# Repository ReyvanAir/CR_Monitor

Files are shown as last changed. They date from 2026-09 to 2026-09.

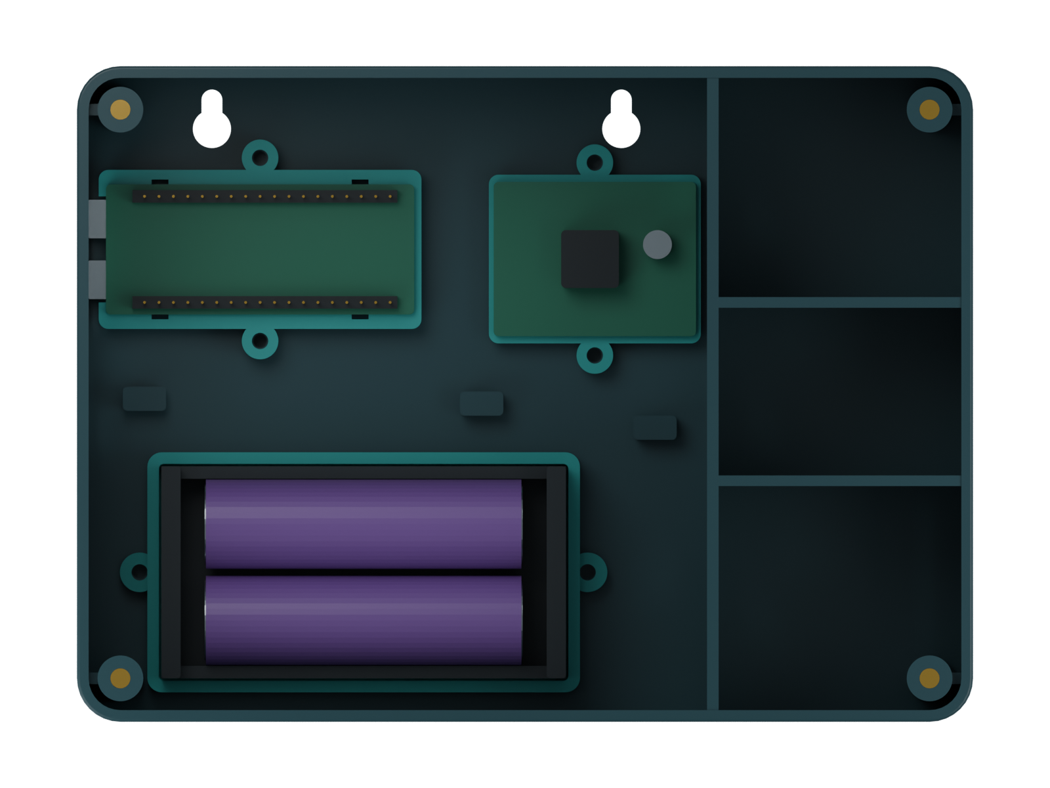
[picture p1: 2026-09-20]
CR_Monitor_Enclosure/previews/03_internal_layout.png

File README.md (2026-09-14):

# Classroom Environment Monitor

An IoT system that measures classroom conditions — temperature, humidity, light and
sound level — and pairs those objective readings with anonymous human feedback, so
decisions about the learning environment can be based on evidence rather than guesswork.

An ESP32-S3 node samples its sensors and publishes JSON telemetry over MQTT. A local
Docker stack (Mosquitto → Node-RED → InfluxDB → Grafana) validates, stores and
visualises the stream.

## Documentation

**[Read the full documentation](https://reyvanair.github.io/CR_Monitor/)**

Five parts, covering the whole build:

| | |
|---|---|
| [Overview](https://reyvanair.github.io/CR_Monitor/) | Architecture, what it measures, project stages |
| [Pins & wiring](https://reyvanair.github.io/CR_Monitor/hardware.html) | Full GPIO map, sensors, display shield |
| [Firmware](https://reyvanair.github.io/CR_Monitor/firmware.html) | Boot order, sampling loop, sound maths, alarms |
| [MQTT contract](https://reyvanair.github.io/CR_Monitor/mqtt.html) | Topics, payload schema, retained state |
| [Build & bring-up](https://reyvanair.github.io/CR_Monitor/setup.html) | Toolchain, flashing, calibration, backend |

The same pages are in [`docs/`](docs/) and open offline straight from the filesystem.

## Hardware

| Part | Function | Connection |
|---|---|---|
| ESP32-S3 DevKitC-1 (N16R8) | Controller | — |
| SHT3x | Temperature + humidity | I²C `0x44` — SDA `GPIO8`, SCL `GPIO9` |
| BH1750 | Illuminance (lux) | I²C `0x23` — same bus |
| MAX4466 | Sound level (dB) | `GPIO5` (ADC1), **3.3 V only** |
| Piezo buzzer | Threshold alert | `GPIO7` |

The mic must stay on an ADC1 pin — ADC2 stops working whenever Wi-Fi is on. Full
wiring notes, rationale and the history of dropped parts (DHT22, the dead I²C LCD)
are in [`CR_Monitor_NOTES.txt`](CR_Monitor_NOTES.txt).

## Privacy

Sound is captured as a **decibel level only**. No audio is recorded, buffered or
transmitted. Occupancy is likewise reported as a bucket (Unoccupied / Low / Medium /
High) rather than a headcount. Both are deliberate design choices, not limitations.

## Repository layout

```
CR_Monitor/CR_Monitor.ino   ESP32-S3 sketch — sensors, Wi-Fi, MQTT
CR_Monitor_NOTES.txt        Design notes: wiring, decisions, the "why"
SETUP_GUIDE.txt             Step-by-step build and deployment guide
docs/                       Project documentation (HTML, also served as a site)
docker-compose.yml          Mosquitto + InfluxDB + Node-RED + Grafana
mosquitto.conf              Broker config (anonymous — LAN use only)
diagram.json                Wokwi simulation layout
```

## Getting started

**1 — Flash the node.** Open `CR_Monitor/CR_Monitor.ino` in the Arduino IDE as board
*ESP32S3 Dev Module* (PSRAM: OPI, Flash: 16 MB). Install the `Adafruit SHT31`,
`BH1750` and `PubSubClient` libraries, then fill in the config at the top:

```cpp
const char* WIFI_SSID     = "YOUR_WIFI_SSID";
const char* WIFI_PASSWORD = "YOUR_WIFI_PASSWORD";
const char* MQTT_HOST     = "192.168.1.5";   // your broker's LAN IP
const char* ROOM_ID       = "room-101";
```

**2 — Start the backend.**

```bash
docker compose up -d
```

Grafana lands on <http://localhost:3000> (`admin` / `admin`), Node-RED on
<http://localhost:1880>, InfluxDB on <http://localhost:8086>.

**3 — Watch the data.** Telemetry publishes to `classroom/<room>/<node>/telemetry`,
with `status` and `alert` on sibling topics.

`SETUP_GUIDE.txt` walks through all of this in detail, including the Node-RED flow
and the InfluxDB token setup.

## Security note

The credentials in the sketch are placeholders — put your own in locally and keep
them out of commits. The broker ships with `allow_anonymous true` for convenience on
a trusted LAN; add authentication before deploying anywhere real.

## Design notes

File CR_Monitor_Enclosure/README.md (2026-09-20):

# CR Monitor enclosure — revision A

Editable Blender 4.5 LTS enclosure for the hardware documented at [Classroom Environment Monitor](https://reyvanair.github.io/CR_Monitor/), revision 2026-09-13.

**Status: dimensioned prototype.** The documentation identifies the hardware and wiring but does not supply mechanical drawings, breakout-board variants, a battery holder, or a battery power circuit. The component sizes below are explicit design assumptions. Digital mesh and interference checks do not establish a physical fit.

## Open the design

Open **CR_Monitor_Enclosure.blend** in Blender 4.5 or newer. The active scene is `CR Monitor | assembled`.

- **Frame 1:** assembled enclosure. **Frame 80:** exploded view. Drag the timeline between them to open the assembly.
- Press **Numpad 0** for the camera view. Camera markers switch between the assembled and exploded cameras.
- Collections `01`, `02`, and `03` contain the printable parts.
- Collections `04` and `05` contain reference hardware and visual legends. They are not printable components.
- Collection `06` contains hidden wireframe fit envelopes. Unhide its objects to inspect the assumed spaces, at frame 1.
- Read `START HERE — design notes` in Blender's Text Editor. The generator is also embedded as `build_enclosure.py`.

The model uses **millimetres**. STL files are already centered and placed on Z = 0 in their intended print orientations. The front bezel is exported face down. Do not apply an additional 1,000× conversion when importing an STL into a slicer.

## Dimensions and layout

| Feature | Design value |
|---|---:|
| Outside enclosure, width × height × depth | **186 × 136 × 62 mm** |
| Rear shell side walls / rear floor | 2.4 / 3.0 mm |
| Front face thickness | 3.0 mm |
| Seam between shell and face | 0.30 mm |
| Registration skirt clearance | 0.35 mm per side |
| LCD opening, landscape | 76 × 51 mm |
| Shared ESP32 USB opening, height × width along the left wall | 16 × 31 mm |
| Separate power-cable opening, height × width | 10 × 14 mm |
| BH1750 opening | 22 × 16 mm |
| MAX4466 sound port | 8 mm diameter |
| SHT3x front grille | Seven 29 × 2 mm slots |
| Buzzer cup / assumed buzzer | 13.4 mm bore / 12 mm diameter |
| Rear wall-mount keyholes | 85 mm horizontal spacing; 8 mm entry, 4.4 mm neck |

The TFT occupies the upper left of the front. The ESP32 sits behind it, with USB connections on the left. The battery holder sits lower left. A separate carrier above the batteries reserves space for the chosen power electronics. Three compartments on the right place BH1750 at the top, MAX4466 in the middle, and SHT3x at the bottom. The temperature/humidity compartment has front, side and bottom vents, separated from the main electronics by a wall with small wire passages.

## Measure these parts before printing

These are **assumed envelopes**, not dimensions verified against your physical parts. Sensor names refer to the full breakout boards, not just their ICs.

| Part | Assumed size / position | Required fit check |
|---|---|---|
| ILI9481 3.5-inch Uno-style shield | PCB 98 × 64 × 1.6 mm; glass 84 × 57 × 4.6 mm; active area 73.9 × 49.3 mm | Measure PCB, glass, active-area offset, all headers and plugged-in connector depth. |
| ESP32-S3 DevKitC-1 N16R8 | PCB 64 × 27 mm | Measure the board, USB positions, header direction, shield thickness and buttons. |
| Purchased two-cell 18650 holder | 84 × 44 × 23 mm maximum nominal envelope | Measure the complete insulated holder with the chosen cells installed, including contacts and leads. |
| Two cell proxies | Diameter 18.6 mm; length 65.5 mm | Protected/button-top cells may be longer. The actual holder determines compatibility. |
| BH1750 breakout | 31 × 16 mm | Verify the light-sensitive element lines up with the opening. |
| MAX4466 breakout | 20 × 14 mm; capsule 9.6 mm diameter × 5.5 mm high | Verify capsule position, gain trimmer, headers and gasket clearance. |
| SHT3x breakout | 23 × 18 mm | Verify sensing element and connector positions; leave the sensing area uncovered. |
| Power electronics | Reserved envelope 42 × 32 × 20 mm | Choose and measure the real module(s), including wires. This is not a specified charger design. |

The TFT's assumed connected-header envelope reaches 19 mm below its PCB, to Z = 33.6 mm. The holder envelope ends at Z = 30.4 mm; the ESP32 wire envelope ends at Z = 27 mm. These leave **3.2 mm** and **6.6 mm** respectively in depth, before any additional cable bends. Check the real plug housings and route the wiring in the open channels. An overall clearance is not a guarantee that every connector orientation fits.

The ESP32 is mounted **component side toward the rear, long header pins toward the TFT**. Its open carrier clears the underside module and USB bodies. Two small rear probe holes assume button centers at X = −78 mm, Y = 25 and 35 mm. Move or omit these holes if your button locations differ. Keep the antenna end clear of the power module, cells and bundled wiring.

## Printable parts

Print one of each of the **12 STL files**:

| Files | Purpose |
|---|---|
| `01_rear_tray.stl` | Rear shell, reinforced case bosses, partitions, vents, rear keyholes and mount bosses |
| `02_front_bezel.stl` | LCD and sensor openings, registration skirt, display/sensor posts and buzzer cup |
| `03_battery_cradle.stl` | Removable cradle for the purchased insulated holder; two strap positions |
| `04_esp32_carrier.stl` | Open carrier, USB relief and tie slots |
| `05_power_carrier.stl` | Separate removable power-module carrier |
| Four `06_tft_clamp_*.stl` files | Slotted PCB-edge retainers; approximately ±1.5 mm screw travel |
| Three `07_*_carrier.stl` files | Sensor-specific open carriers, edge guides and tie slots |

PETG is a reasonable prototype material. A starting slicer setup is a 0.4 mm nozzle, 0.2 mm layers, four walls and five top/bottom layers. Adjust supports for the horizontal vent/USB bridges after checking your slicer preview. The main parts fit within a nominal 220 × 220 mm print bed. Printed legends and the sample screen are visualizations only; they are not raised lettering in the STL files.

The four main case bosses have **4.2 mm bores, 5.7 mm deep**, for suitably sized M3 heat-set inserts. Match the bores to the actual insert manufacturer's specification. Internal mount pilots are nominally 2.8 mm: confirm grip with the selected M3 plastic thread-forming screws and printed material before assembly. Do not assume every M3 screw/insert has the same fit.

## Assembly

1. Check dimensions and slicer scale, then test-print the smallest relevant carrier/clamp before the shells. Verify the intended screw/insert fit on scrap material.
2. Install the four M3 case inserts. Install the ESP32 and power carriers. Secure electronics at clear PCB edges with nonconductive ties, appropriate shims and insulation; keep solder joints off printed supports.
3. Fit the purchased holder in its cradle. Use straps through the side-wall passages. The printed cradle supplies mechanical retention, **not electrical contacts**.
4. Place the display behind the front bezel. Use a thin compressible strip at the glass perimeter and approximately 0.2 mm shims between the PCB back and retaining fingers. Adjust the four fingers to touch bare PCB edges, clear of components, headers and the active touch surface. Tighten gently.
5. Attach the three sensors to their carriers and align the sensing elements with their openings. Use narrow nonconductive ties at the provided edge positions. Keep the SHT3x unobstructed. A soft gasket around the microphone capsule can couple it to the port. Secure the piezo in its cup using suitable foam tape.
6. Route sensor wires through the partition passages. Keep the parallel TFT bus short, allow enough movement to service the front, and use the documented grounds. Route the chosen power input through the separate cable opening and secure the cable to a nearby anchor.
7. Check all connectors and wire bends with the bezel resting in place. Close with four appropriately sized M3 countersunk screws. Fit wall screws to the rear keyholes, or stand the enclosure on its bottom edge with vents unobstructed.

Suggested fasteners are **starting selections to verify**, not a guarantee for every screw head or printed thread: four M3 × 10 countersunk case screws; four M3 × 8 TFT clamp screws; two M3 × 6 BH1750 screws; two M3 × 8 SHT3x screws; two M3 × 10 MAX4466 screws. Rear carrier and cradle screws need short engagement; use washers as necessary and check blind-hole depth so the tips cannot bottom out or penetrate the rear floor. Hardware, ties, gaskets and insulation are not supplied as printable parts.

## Electrical and sensing integration

The [hardware documentation](https://reyvanair.github.io/CR_Monitor/hardware.html) specifies SHT3x and BH1750 on GPIO8/9, MAX4466 on GPIO5 and the buzzer on GPIO7. The ILI9481 shield uses the documented parallel bus, a 5 V backlight supply and, for this particular shield, a separate 3.3 V logic supply. The enclosure does not change those connections.

The source does **not** specify how the two 18650 cells are connected or charged. Select a compatible insulated holder, cell arrangement, protection/charging and regulated supply before assembly. Do not connect the raw cells directly to a rail labeled 5 V or 3V3. The power-board shape in Blender only reserves space.

After assembly, compare SHT3x readings with an external reference during warm-up, recheck light readings in the intended mounting orientation, and recalibrate the microphone with the case closed. Check whether the buzzer affects sound readings. Do not cover the BH1750 opening with tinted plastic without validating its effect. The open sensor ports make this an indoor ventilated prototype, not a weatherproof enclosure.

## Edit and regenerate

Edit the `P` dictionary in `build_enclosure.py`, then run it in Blender's Scripting workspace or with `blender --background --python build_enclosure.py`. The script creates a new scene and preserves existing scenes. `CR_MONITOR_OUTPUT` can specify an output folder. Set `render` to `False` to skip preview renders.

`parameters.json` is an exported record of assumptions; editing that JSON alone does not regenerate the model. Major changes to board sizes, depth or layout also require checking the carrier positions, posts, connector openings and wire spaces in the script. Always re-inspect the assembled result after edits.

`validation_report.json` records digital checks of closed meshes, connected solids, normals, modeled part interference and the exploded animation. It does not certify print tolerances, physical component fit, thermal performance or battery behavior.

Sources: [overview](https://reyvanair.github.io/CR_Monitor/), [pins and hardware](https://reyvanair.github.io/CR_Monitor/hardware.html), [firmware](https://reyvanair.github.io/CR_Monitor/firmware.html), and [display wiring notes](https://github.com/reyvanair/CR_Monitor/blob/main/WIRING_TFT.md). Read on 2026-09-14.

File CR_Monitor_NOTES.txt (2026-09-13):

======================================================================
CR_Monitor - DESIGN NOTES
Classroom Environment Monitor, Stage 2 (real hardware)
======================================================================

This file holds the "why" that used to live as long comments inside
CR_Monitor.cpp. The code now only carries short section headers
(PINS, WI-FI, MQTT, SOUND, ...). Read this alongside it.

Board:  ESP32-S3 DevKitC-1 (N16R8)
  Arduino IDE:  Tools > Board > "ESP32S3 Dev Module"
                PSRAM: "OPI PSRAM"   Flash Size: "16MB"

Libraries (Library Manager):
  - Adafruit SHT31 Library   (Adafruit)      + Adafruit BusIO
  - BH1750                    (Christopher Laws)
  - PubSubClient              (Nick O'Leary)

----------------------------------------------------------------------
1. WIRING
----------------------------------------------------------------------

I2C bus - SDA = GPIO8, SCL = GPIO9:
    SHT3x    addr 0x44 (ADDR->GND) or 0x45 (ADDR->VDD)   power 3.3V
    BH1750   addr 0x23 (ADDR->GND) or 0x5C (ADDR->VDD)   power 3.3V
  Both wired straight to GPIO 8/9 on the 3.3V side.
  Run the I2C bus at 100 kHz (Wire.setClock(100000)).

MAX4466 microphone:
    VCC -> 3.3V   (NOT 5V - the output centres at VCC/2; on 5V it
                   swings past the ESP32 ADC's 3.3V limit and can
                   damage the pin)
    OUT -> GPIO5  (MIC_PIN)
    GND -> GND    (must share ground with the ESP32)

  GPIO5 must be an ADC1 pin. ADC2 stops working whenever Wi-Fi is on,
  so the mic cannot move to an ADC2 pin.

Buzzer:
    + -> GPIO7 (BUZZER_PIN)
    - -> GND
  A piezo buzzer can be driven directly. A magnetic buzzer needs a
  transistor plus a flyback diode.

LCD (currently NOT used):
  The 20x4 I2C LCD backpack is dead / not wired. Everything it used to
  show is printed to the Serial monitor instead (the "status panel").
  The backpack also pulls SDA/SCL to 5V and the ESP32-S3 is not 5V
  tolerant - if the LCD comes back it needs a bidirectional level
  shifter between GPIO 8/9 and the LCD (LV->3V3, HV->5V, common GND),
  with the SHT3x and BH1750 staying on the 3.3V side.
  To re-enable: add <LiquidCrystal_I2C.h>, the lcd object, lcd.init()
  in setup(), and feed the panel fields to lcd rows.

History: the DHT22 was removed. The SHT3x replaces it and speaks I2C,
which got rid of the bit-banged timing that never worked reliably on
the ESP32-S3. GPIO4 and GPIO6 are now free.

----------------------------------------------------------------------
2. PINS  (matches the PINS block in the code)
----------------------------------------------------------------------

  I2C_SDA    = 8
  I2C_SCL    = 9
  MIC_PIN    = 5   (ADC1 only)
  BUZZER_PIN = 7

  SHT3X_ADDR  = 0x44   (0x45 if the ADDR pin is tied high)
  BH1750_ADDR = 0x23   (0x5C if the ADDR pin is tied high)

----------------------------------------------------------------------
3. WI-FI  (state machine)
----------------------------------------------------------------------

handleWifi() is called once per loop() and never blocks. States:

    SCAN --(SSID seen)--> CONNECTING --(connected)--> CONNECTED
     ^                        |                           |
     |                 (timeout / fail)              (link drops)
     |                        v                           v
     +-------------------- WAIT_RETRY <-------------------+

  SCAN        - scan for the configured SSID; if present, WiFi.begin().
  CONNECTING  - wait up to WIFI_CONNECT_TIMEOUT_MS (15 s) for a link.
  CONNECTED   - steady state; drop back to WAIT_RETRY if the link dies.
  WAIT_RETRY  - hold for WIFI_RETRY_DELAY_MS (5 s), then SCAN again.

Sensors and the buzzer keep working in every state. This is
deliberate: the local audible alarm must NOT depend on the LAN.

Set WIFI_SSID / WIFI_PASSWORD at the top of the code.

----------------------------------------------------------------------
4. MQTT  (Stage 2 transport)
----------------------------------------------------------------------

The ESP32 only PUBLISHES. Validation, the "official" alert rules, the
occupancy merge and storage all live in Node-RED downstream. Keep this
node dumb: sample, package, publish.

Client: PubSubClient over a plain WiFiClient. mqttService() runs once
per loop(), downstream of the Wi-Fi state machine - it does nothing
until Wi-Fi is CONNECTED, and never blocks longer than ~3 s
(setSocketTimeout(3)) when the broker is unreachable. It retries every
MQTT_RECONNECT_MS (5 s).

Config (top of code):
  MQTT_HOST   - broker IP or hostname on the LAN
  MQTT_PORT   - 1883 (plaintext). Use 8883 + TLS before real deployment.
  MQTT_USER / MQTT_PASS  -  "" = anonymous (LAN testing only)
  ROOM_ID     - set per room, e.g. "room-101"

Node id: the low 3 bytes of the MAC, hex. Each board self-names, so
you can add more nodes without editing anything.

Topics (namespaced so more nodes / subscribers can be added freely):

  classroom/<room>/<node>/telemetry
      JSON sensor reading, published every READ_INTERVAL_MS (2 s).
      QoS 0 (a dropped 2-second sample does not matter).
      Fields:
        ts               epoch seconds (0 until NTP has synced)
        ts_valid         true once the clock is real
        uptime_ms        millis() since boot
        seq              incrementing counter - lets Node-RED spot gaps
        temp_c, hum_pct  null when the SHT3x read failed
        lux              null when the BH1750 read failed
        sound_avg_db     continuous level (trend analysis)
        sound_peak_db    loudest transient (exceedance analysis)
        sound_calibrated false until MIC_CAL_DB is set - trust flag
        alerts           3 chars, e.g. "T-S" (temp+sound), "---" = none
        rssi             Wi-Fi signal, dBm

  classroom/<room>/<node>/status
      "online" / "offline", RETAINED.
      "online" is published on connect. "offline" is the MQTT Last
      Will - the broker publishes it automatically if the node drops
      off the network (after the keepalive lapses). This is how the
      dashboard tells "room is quiet" from "node is dead".

  classroom/<room>/<node>/alert
      Current alert state as JSON {"temp":bool,"light":bool,"sound":bool},
      RETAINED. Published only when the combined state changes (or on
      reconnect), so a subscriber that joins late still gets it.

PubSubClient only does QoS 0. The retained status/alert topics cover
the "must not be missed" cases instead. If you later need guaranteed
alert delivery, switch to the 256dpi/arduino-mqtt library.

----------------------------------------------------------------------
5. TIME (NTP)
----------------------------------------------------------------------

millis() resets on every reboot, so it is useless for aligning sensor
records with the occupancy bucket and the feedback form. configTime()
in setup() starts an SNTP sync the moment Wi-Fi comes up; timeValid()
returns true once the clock is past TIME_VALID_MIN (2023-11-14) - i.e.
actually set rather than sitting at the 1970 epoch.

Store UTC (GMT_OFFSET_SEC = 0). Convert to local time in Grafana.

----------------------------------------------------------------------
6. THRESHOLDS + HYSTERESIS
----------------------------------------------------------------------

TEMP_MAX_C / TEMP_MIN_C, LUX_MIN / LUX_MAX, SOUND_MAX_DB are
PLACEHOLDERS. Before collecting real data, justify each against a
cited standard - local building code, ASHRAE 55 for thermal comfort,
EN 12464-1 for lighting - and record the citation in the methodology.

Hysteresis (TEMP_HYST, LUX_HYST, SOUND_HYST): once an alarm is
latched, the reading must come back this far INSIDE the band before it
clears. This stops the alarm chattering when a value sits exactly on
the limit, and stops one real event being logged as dozens of
separate exceedances.

Note: these local buzzer thresholds now DUPLICATE the alert rules that
Node-RED will apply. Either keep them in sync, or treat the on-board
ones as a deliberately looser "something is badly wrong" trigger and
document that choice.

----------------------------------------------------------------------
7. SOUND MEASUREMENT + CALIBRATION   (important)
----------------------------------------------------------------------

The MAX4466 is a bare electret microphone plus an amplifier. It is NOT
a sound-level meter. Everything past its output voltage is assumption.
Report it as a "relative acoustic level, calibrated at two points",
never as a certified dB(A) figure.

How the number is built:
  1. calibrateMicBias() at boot averages ~2000 samples with the room
     quiet to find the DC operating point (~VCC/2, ~1.65 V, ~2048
     counts). Stored in micBias.
  2. readSound() samples MIC_PIN for MIC_WINDOW_MS (100 ms), split
     into 10 ms sub-windows. Per sub-window it computes the RMS of
     (sample - micBias) - i.e. the AC part only.
  3. Each sub-window RMS is converted to dB:
        dB = 20*log10(Vrms / MIC_REF_V) + MIC_DB_OFFSET + MIC_CAL_DB
     Sub-window dBs are averaged (soundAvgDb) and maxed (soundMaxDb).
  4. ESP32 analogRead() occasionally glitches to 0 or 4095, worse with
     Wi-Fi on. Those samples are dropped - one spike wrecks the RMS.

Why MIC_CAL_DB is mandatory:
  MIC_REF_V (6.31 mV/Pa) and MIC_DB_OFFSET (94) describe the BARE
  electret. The module's gain trimpot multiplies the signal 25x-125x,
  which adds a fixed +28..+42 dB error. Uncalibrated, a ~40 dB room
  reads ~115 dB. MIC_CAL_DB is the correction.

  Current value: MIC_CAL_DB = -77.0  (set 2026-08-28: panel showed
  ~116 dB in a room measured at ~39 dB, so 39 - 116).

One-point calibration procedure (quiet end):
  1. Set MIC_CAL_DB = 0, flash, let the room be quiet.
  2. Note the steady "avg" dB from the status panel.
  3. Measure the real level with an SPL meter / phone app (a quiet
     room is ~35-40 dB).
  4. MIC_CAL_DB = (real_dB - panel_dB). Flash again.

Verify at the loud end:
  Play a steady tone / run a noisy appliance, compare panel vs meter.
   - Off by a CONSTANT amount everywhere -> adjust MIC_CAL_DB.
   - Fine when quiet, wrong when loud -> the amp is CLIPPING. Turn the
     gain trimpot down (counter-clockwise ~1/2 turn) and redo the
     quiet calibration.

SOUND_DEBUG:
  When true (default), readSound() prints a raw line each read:
    # mic raw: mean=1925 min=1719 max=2077 p-p=358  (bias=1922)
  Use it to check wiring BEFORE trusting any dB value:
    connected, quiet   : mean ~1900-2100, p-p a few tens
    connected, clap    : p-p jumps to hundreds / thousands
    disconnected       : mean drifts, p-p large & random  <- floating
                         pin, NOT a real 140 dB
  Set SOUND_DEBUG false once you trust the setup, to quiet the log.

The sound alarm (buzzer) stays disabled until MIC_CAL_DB != 0, because
an uncalibrated level would trip it constantly. It still logs and
publishes the whole time.

avg vs peak: sound is bursty. avg approximates a continuous level for
trend analysis; peak catches transients for exceedance analysis. Both
are logged and published. Peak drives the alarm - a loud transient is
what people in the room actually notice.

----------------------------------------------------------------------
8. BUZZER (non-blocking beeper)
----------------------------------------------------------------------

startAlarm(beeps, freq) queues a pattern; serviceAlarm() (called every
loop pass) steps it using millis(), no delay(). A delay() here would
stall the sensor loop and the MQTT client mid-publish.

  temp alert  : 3 beeps @ 2200 Hz
  light alert : 2 beeps @ 1200 Hz
  sound alert : 4 beeps @ 1700 Hz
  boot        : 2 beeps @ 1500 Hz  (also a buzzer self-test)

A new pattern is ignored until the current one finishes.

----------------------------------------------------------------------
9. SERIAL OUTPUT
----------------------------------------------------------------------

Two things print every READ_INTERVAL_MS at 115200 baud:

  a) Status panel - human readable, the old LCD content:
       +------------------------------+
       | Classroom Monitor
       | Temp : 24.3 C
       | Humid: 46.7 %
       | Light: 420 lx
       | Sound: 58 dB peak (avg 47 dB, 3.21 mVrms)
       | Wi-Fi: connected
       | MQTT : connected, seq 42, time ok
       +------------------------------+

  b) CSV line - for local logging / spreadsheet import:
       time_ms,temp_c,humidity_pct,lux,sound_avg_db,sound_peak_db,alerts
       12345,24.30,46.70,420.0,47.2,58.1,---

Lines beginning with '#' are diagnostics (read failures, alerts,
mic raw stats), not data.

The CSV is independent of MQTT - it keeps working with no network.

----------------------------------------------------------------------
10. LOOP STRUCTURE
----------------------------------------------------------------------

Every pass (fast, non-blocking):
    serviceAlarm()   - step the buzzer pattern
    handleWifi()     - advance the Wi-Fi state machine
    mqttService()    - keep the MQTT link up / reconnect

Every READ_INTERVAL_MS (2 s):
    read SHT3x, BH1750, MAX4466
    evaluateAlarms() - latch/clear temp, light, sound alarms
    publishAlertState() - retained MQTT, only on change
    printPanel()     - status panel to Serial
    print CSV line
    publishTelemetry() - JSON to MQTT (no-op if the link is down)

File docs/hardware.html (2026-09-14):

Classroom Environment Monitor ESP32-S3 · rev 2026-09-13

On this page

The pin budget Sensors and buzzer Display shield Leave unconnected Optional microSD The regulator problem Wiring practice

Pins & wiring

# Every connection, and why it lands where it does

The ESP32-S3 DevKitC-1 N16R8 advertises 45 usable GPIOs. By the time the flash, the PSRAM, the USB pair, the serial console and the ADC2 restriction have taken their share, the display's thirteen signals fit with almost nothing to spare. Nearly every pin choice on this board is forced. This page records what forced it.

#### Before you wire anything

Both boards present male pins, so every jumper here is female to female. Shield labels are read from its own silkscreen (headers J1 to J4); ESP32 numbers are the GPIO numbers printed on the DevKitC-1.

## The pin budget

Four constraints eliminate most of the map before any design choice is made:

- GPIO 26 to 32 are the SPI flash and 33 to 37 are the OPI PSRAM, which is what the "R8" in N16R8 means. Twelve pins gone, permanently.
- GPIO 22 to 25 do not exist on the S3 package. They are absent, not reserved.
- GPIO 43 and 44 carry UART0, which is the serial CSV output; 19 and 20 are USB; 0, 45 and 46 are strapping pins sampled at reset.
- ADC2 stops converting whenever Wi-Fi is on. Anything analogue has to sit on ADC1, meaning GPIO 1 to 10.

Where all 49 positions go. After the display is wired, six pins remain free: GPIO 3, 4, 6, 40, 48 and whichever of the microSD group you decline to use. GPIO48 drives the DevKitC-1 onboard RGB LED, which is why the optional SD chip select is 41 rather than the more obvious 48.

## Sensors and buzzer

Two sensors share one I²C bus; the microphone is analogue and the buzzer is a tone output. This group was wired first and has not moved since.

Part | Signal | ESP32-S3 | Supply | Notes
SHT3x temp + humidity | SDA | 8 | 3.3 V | Address 0x44 with ADDR to GND, 0x45 to VDD. Bus runs at 100 kHz.
| SCL | 9
BH1750 illuminance | SDA | 8 | 3.3 V | Address 0x23 with ADDR to GND, 0x5C to VDD. Same two wires as the SHT3x.
| SCL | 9
MAX4466 electret mic | OUT | 5 | 3.3 V | Must be ADC1. Must share ground with the ESP32.
Piezo buzzer | + | 7 | GPIO | Driven with tone(). Three patterns, one per alarm type.

#### Do not run the MAX4466 from 5 V

Its output centres at half its supply rail. On 5 V that puts the quiescent point at 2.5 V and swings peaks past the 3.3 V the ESP32 ADC can accept, which can damage the pin. On 3.3 V the centre is 1.65 V, roughly 2048 counts, which is exactly what the boot self-test checks for.

## Display shield

A 3.5 inch 320×480 ILI9481 panel in Arduino Uno shield form factor, hand wired to the ESP32 rather than plugged in. Thirteen signals plus power, across four headers.

Header | Shield label | Uno pin | ESP32-S3 | Why this pin
J1 | LCD_D0 | D8 | 10 | D0 to D7 sit contiguous in GPIO 10 to 17 so the whole byte is one register write rather than eight pin operations.
J1 | LCD_D1 | D9 | 11
J2 | LCD_D2 | D2 | 12
J2 | LCD_D3 | D3 | 13
J2 | LCD_D4 | D4 | 14
J2 | LCD_D5 | D5 | 15
J2 | LCD_D6 | D6 | 16
J2 | LCD_D7 | D7 | 17
J3 | LCD_RD | A0 | 39 | Read strobe.
J3 | LCD_WR | A1 | 38 | Write strobe. The timing-critical line; keep it short.
J3 | LCD_RS | A2 | 2 | Data/command select. Doubles as touch XM, so it must be ADC1.
J3 | LCD_CS | A3 | 1 | Chip select. Doubles as touch YP, so it must be ADC1.
J3 | LCD_RST | A4 | 42 | Panel reset.
J4 | 5V | 5V | 5V | Backlight rail. Draws roughly 120 to 150 mA.
J4 | 3.3V | 3.3V | 3V3 | Required on this board. It is an input, not an output. See below.
J4 | GND | GND | GND | Mandatory.
J4 | GND | GND | GND | Second ground. Strongly recommended with thirteen switching lines.

#### Why LCD_RS and LCD_CS are pinned to GPIO 2 and 1

On a resistive touch panel these two lines are also the touch layer's XM and YP electrodes, and reading a touch means calling analogRead() on them. That makes them analogue inputs, which puts them under the same ADC1 requirement as the microphone: ADC2 is unavailable while Wi-Fi is running. GPIO 1 and 2 are the only low-numbered pins still free once the mic, buzzer and I²C bus have taken 5, 7, 8 and 9.

## Leave unconnected

Shield pin | Reason
J3 F_CS | Chip select for a W25Q32 flash footprint that is unpopulated on this board.
J4 RESET | Never let the shield pull the ESP32 reset line.
J1 top two | Unlabelled. Uno AREF and GND.
J2 bottom two | Unlabelled. Uno D0 and D1, which are RX and TX.
J4 VIN, IOREF | Not used.

## Optional microSD

The shield breaks out a microSD slot on J1. Wire it only if you want the node to buffer readings to disk while the broker is unreachable. Nothing in the current firmware uses it.

Label | Uno pin | ESP32-S3 | Note
SD_SCK | D13 | 18
SD_DO (MISO) | D12 | 21
SD_DI (MOSI) | D11 | 47
SD_SS | D10 | 41 | 41 and not 48, because GPIO48 drives the onboard RGB LED.

## The regulator problem

Investigation closed 2026-09-13

For a while this display did not work, and the symptom was misleading: the backlight lit normally, the screen stayed permanently white, and reading the controller ID back over the bus returned 0x00 or 0xFF. A lit backlight makes the board look alive, which sent the search toward the driver and the pin map before the power rail.

The backlight runs directly from 5 V. The controller and its bus buffers do not. On a shield with an onboard 3.3 V regulator the J4 3.3V pin is an output and you leave it alone; on a shield without one it is an input, and if you leave it alone the entire logic domain has no supply at all. That is the state this board was in.

### The test

1. Wire 5V and GND only. Nothing else.
2. Power the ESP32 over USB.
3. Measure the shield's 3.3V pin against GND.

Reading | Meaning | Action
~3.3 V | Onboard regulator present | Leave 3.3V unconnected.
0 V | No regulator | Wire shield 3.3V to ESP32 3V3.

#### Result on this board: no regulator

A visual inspection found no AMS1117 or any other 3.3 V part. The only two ICs are U1 and U2, both marked SM245TC, which are octal bus transceivers. So J4 3.3V is an input and must be wired, and the shield's whole logic domain including those buffers sits at 3.3 V.

That last detail also settles a question worth raising on any parallel shield. A plain HC245 running from 5 V has an input threshold near 3.5 V, which the S3's 3.3 V drive would meet only marginally. Here the buffers are powered from the same 3.3 V rail the ESP32 drives, so the levels match by construction and the concern does not apply. If you are wiring a different board, read the markings on its buffers first: LVC245 or ALC245 is fine on 3.3 V logic, and a 5 V-powered HC245 is a reason to stop and reconsider.

## Wiring practice

This is a parallel bus with no error checking. Signal integrity problems do not announce themselves; they show up as occasional wrong pixels, which is easy to blame on software.

- Keep the eight data wires, and LCD_WR above all, short and roughly equal in length. Long floppy jumpers on the write strobe produce glitchy pixels.
- Connect both grounds. Thirteen fast-switching lines need a return path, and a single thin ground wire is not one.
- Budget for the backlight. 120 to 150 mA is comfortable over USB, but leave headroom when moving to a wall adapter.
- Do not disturb GPIO 5, 7, 8, 9, 43 or 44 while rearranging the display wiring. Those are the mic, the buzzer, the I²C bus and the serial console.

#### Confirm the bus before flashing the full sketch

Test_TFT/Test_TFT.ino exists for this. A red screen means the pin map and the bus are correct. White or blank means checking LCD_WR, LCD_CS, LCD_RST and the 3.3 V question, in that order, before suspecting anything in the firmware.

Installing the pin mapTFT_eSPI reads its config from outside this repo Boot self-testWhat the node checks before it trusts any of this

Classroom Environment Monitor · pin map confirmed against shield silkscreen, 2026-09-13

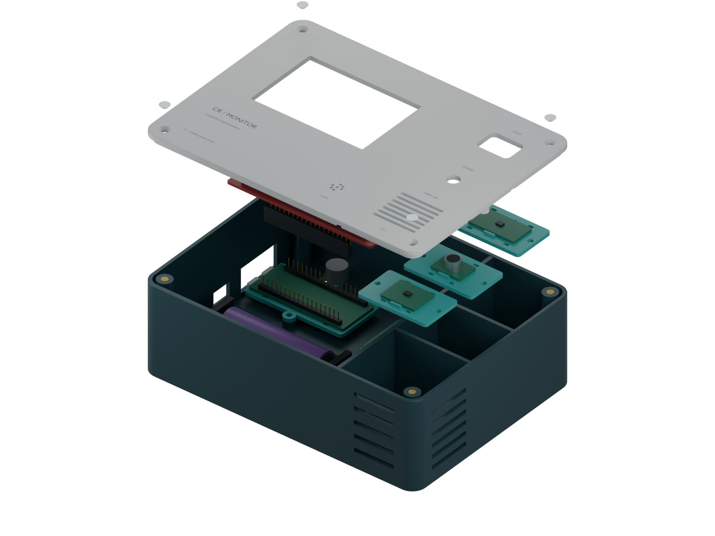
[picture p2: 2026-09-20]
CR_Monitor_Enclosure/previews/04_exploded.png

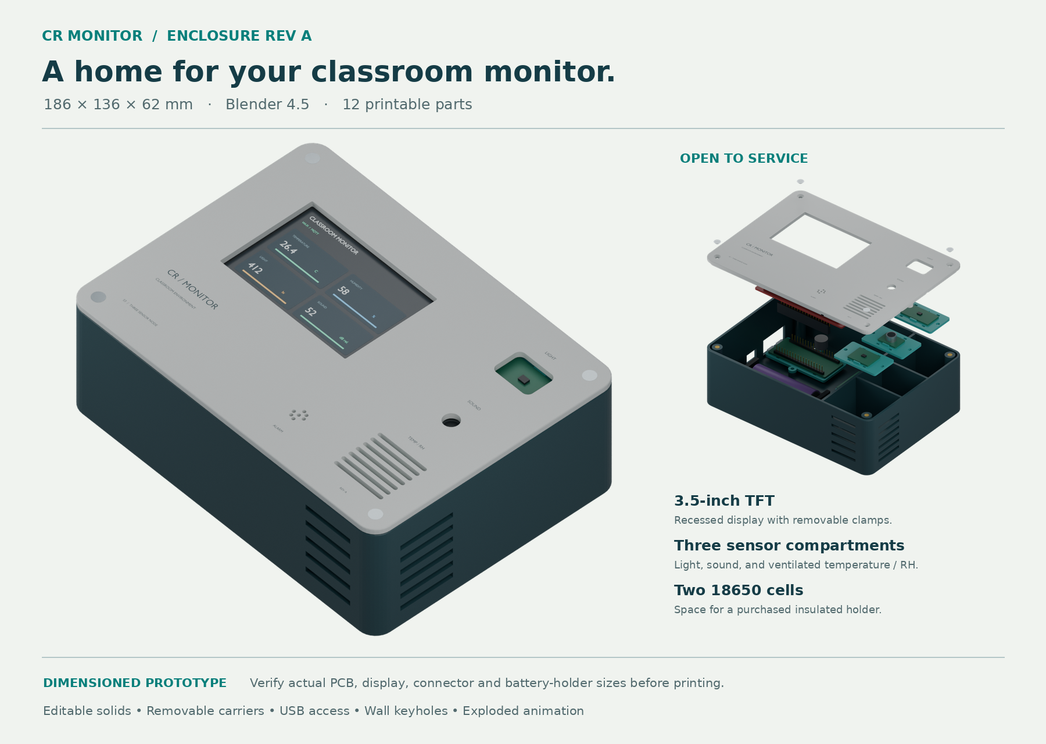
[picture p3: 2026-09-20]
CR_Monitor_Enclosure/CR_Monitor_Preview.png

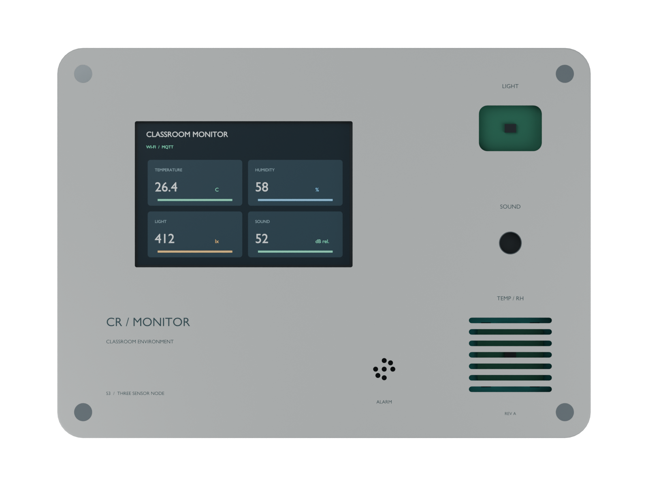
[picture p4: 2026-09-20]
CR_Monitor_Enclosure/previews/02_front.png

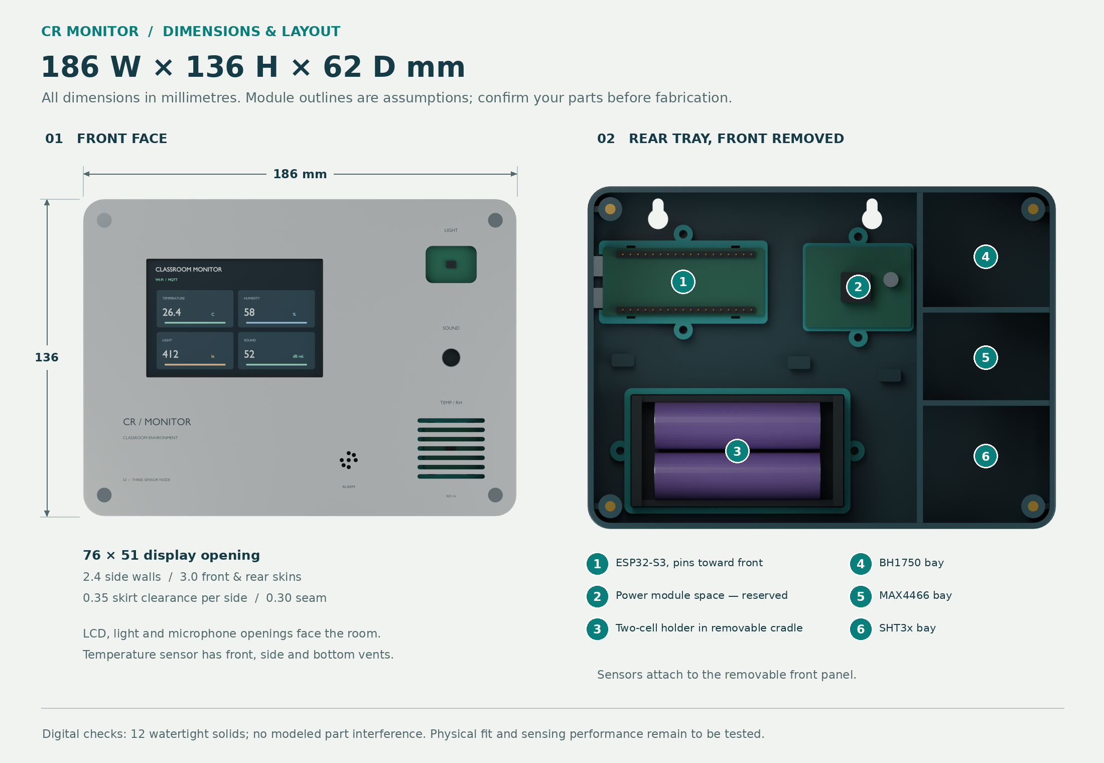
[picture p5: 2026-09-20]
CR_Monitor_Enclosure/Dimensions_and_Internal_Layout.png

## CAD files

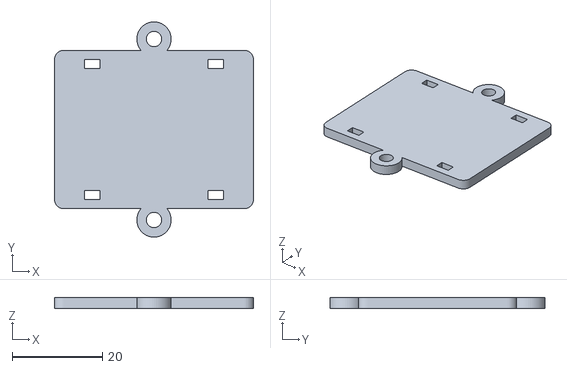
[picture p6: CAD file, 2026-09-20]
CR_Monitor_Enclosure/STL/05_power_carrier.stl
44.0 x 47.6 x 2.40

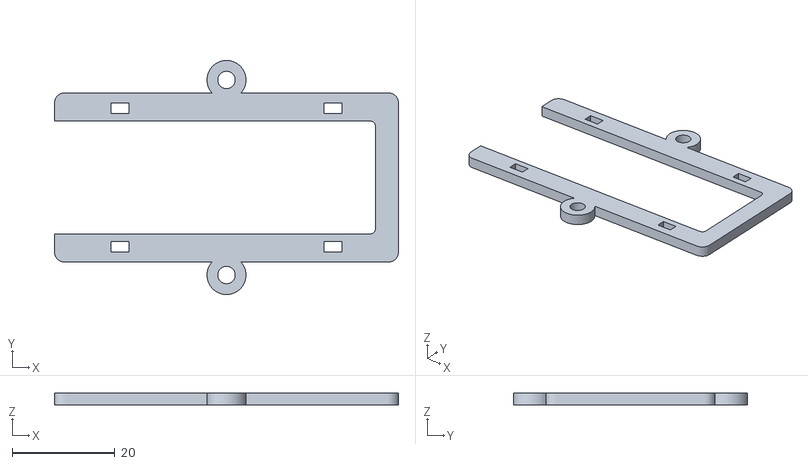
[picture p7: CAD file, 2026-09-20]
CR_Monitor_Enclosure/STL/04_esp32_carrier.stl
67.0 x 45.6 x 2.40

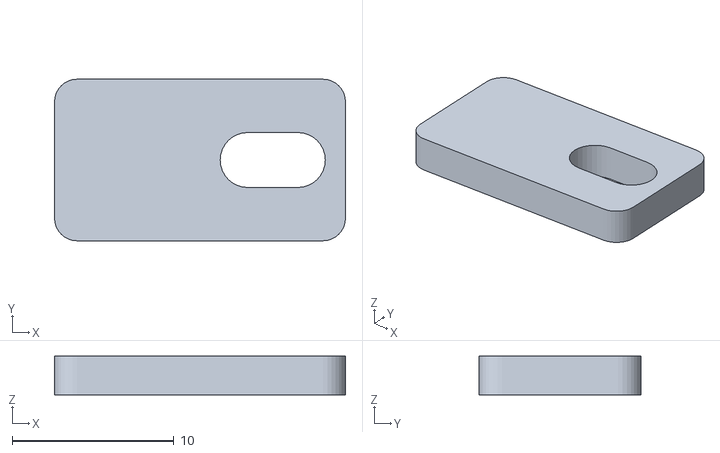
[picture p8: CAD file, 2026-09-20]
CR_Monitor_Enclosure/STL/06_tft_clamp_R_2.stl
18.0 x 10.0 x 2.40

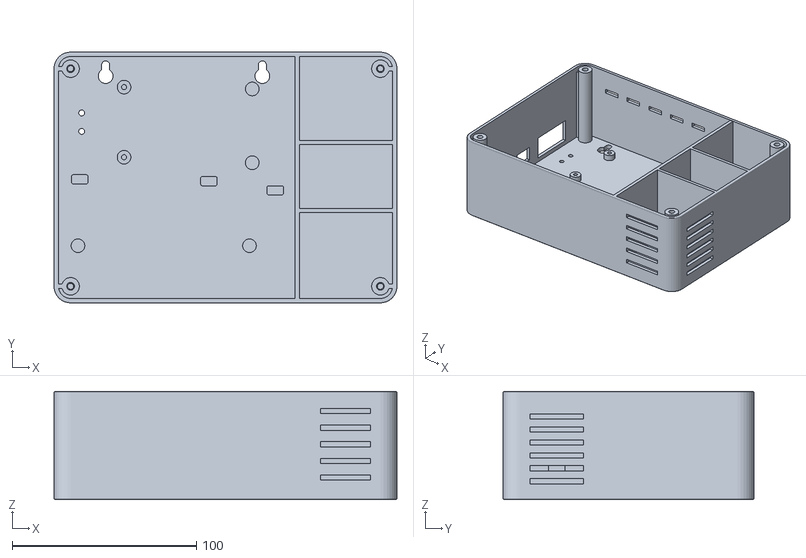
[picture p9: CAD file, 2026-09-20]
CR_Monitor_Enclosure/STL/01_rear_tray.stl
186.0 x 136.0 x 58.7

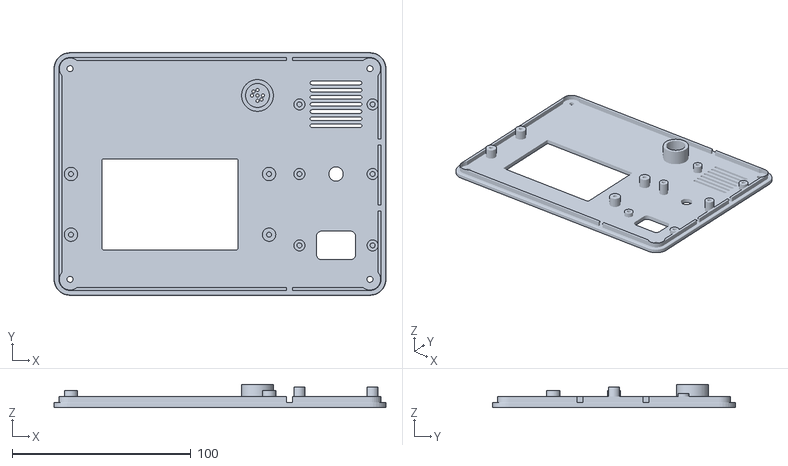
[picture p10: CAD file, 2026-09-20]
CR_Monitor_Enclosure/STL/02_front_bezel.stl
186.0 x 136.0 x 13.1

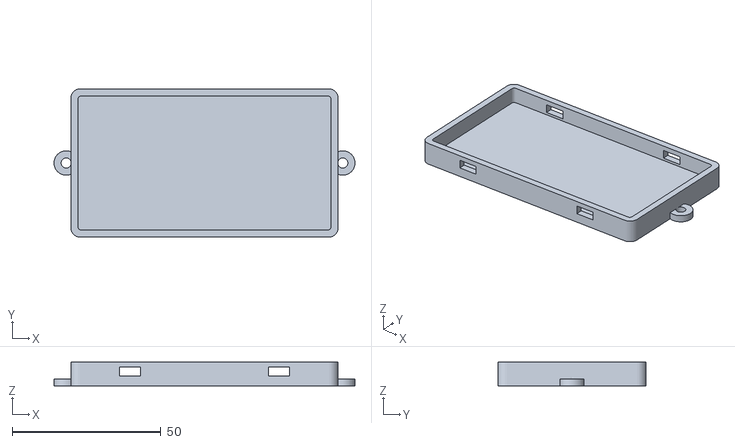
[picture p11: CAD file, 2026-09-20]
CR_Monitor_Enclosure/STL/03_battery_cradle.stl
101.2 x 49.8 x 8.00

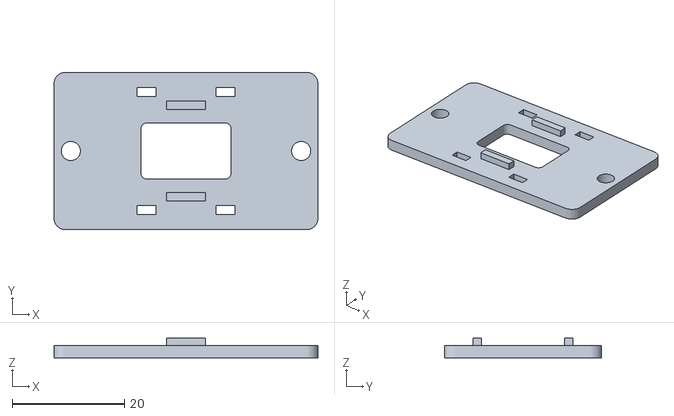
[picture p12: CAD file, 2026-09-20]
CR_Monitor_Enclosure/STL/07_max4466_carrier.stl
47.0 x 28.0 x 3.50

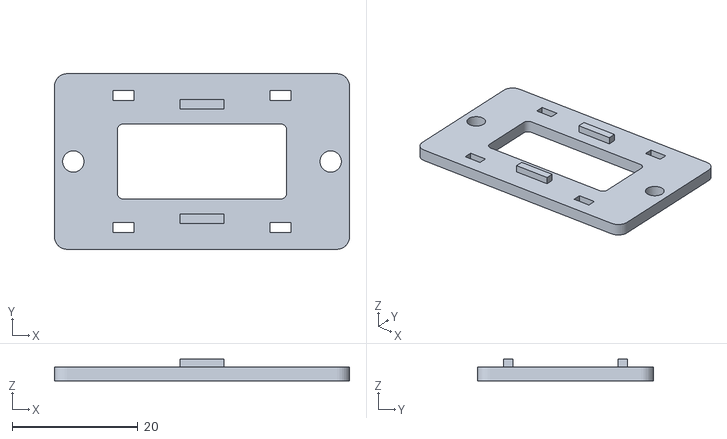
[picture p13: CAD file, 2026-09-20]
CR_Monitor_Enclosure/STL/07_bh1750_carrier.stl
47.0 x 28.0 x 3.50

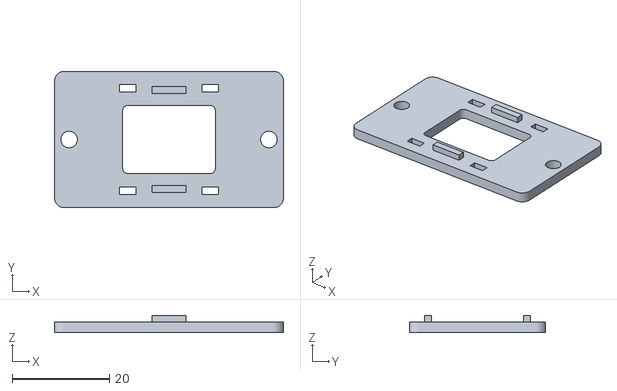
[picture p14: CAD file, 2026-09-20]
CR_Monitor_Enclosure/STL/07_sht3x_carrier.stl
47.0 x 28.0 x 3.50

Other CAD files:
CR_Monitor_Enclosure/STL/06_tft_clamp_L_2.stl
CR_Monitor_Enclosure/STL/06_tft_clamp_R_1.stl
CR_Monitor_Enclosure/STL/06_tft_clamp_L_1.stl
CR_Monitor_Enclosure/CR_Monitor_Enclosure.blend

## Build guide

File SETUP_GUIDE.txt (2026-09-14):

======================================================================
CLASSROOM MONITOR - STAGE 2 & 3 SETUP WALKTHROUGH
From "ESP32 prints to Serial" to "data in a Grafana dashboard"
======================================================================

You have never done this before - that is fine. Follow the parts in
order. Do not skip. Each part ends with a CHECK: do not move on until
the check passes.

What you are building (recap):

  ESP32  --Wi-Fi/MQTT-->  Mosquitto (broker)  -->  Node-RED (clean +
  rules)  -->  InfluxDB (storage)  -->  Grafana (dashboard)

  MQTTX is just a viewer you use to confirm messages are flowing.

Time: about 2-3 hours the first time, most of it waiting on downloads.

Files in this folder that this guide uses:
  docker-compose.yml   - starts the broker + Node-RED + InfluxDB + Grafana
  mosquitto.conf       - broker config (already filled in)
  CR_Monitor.cpp       - the ESP32 sketch
  CR_Monitor_NOTES.txt - design reference

======================================================================
PART 0 - PREREQUISITES
======================================================================

0.1  Find your PC's LAN IP address. Open PowerShell and run:

        ipconfig

     Look for "IPv4 Address" under your active adapter (Wi-Fi or
     Ethernet). It looks like 192.168.1.23 or 10.0.0.5. WRITE IT DOWN
     - this guide calls it  <PC_IP>.

     Your ESP32 and your PC must be on the SAME network (same router,
     same Wi-Fi). A "guest" Wi-Fi usually blocks this - use the main
     one.

0.2  Decide which sketch file is real.

     Your project currently has TWO copies:
        D:\Suvin's Project\CR_Monitor.cpp            <- the one we edit
        D:\Suvin's Project\CR_Monitor\CR_Monitor.ino <- older, stale

     The Arduino IDE compiles a folder named X containing X.ino. So:
       - Make a folder  D:\Suvin's Project\CR_Monitor\
       - Put the CURRENT code in it as  CR_Monitor.ino
       - Easiest: open CR_Monitor.cpp, Select All, Copy. Open
         CR_Monitor\CR_Monitor.ino in the Arduino IDE, Select All,
         Paste, Save.
       - From now on only edit the .ino. Delete or ignore the .cpp so
         you never flash the old version by mistake.

     (If you already do it a different way that works - keep doing
     that. The point is: ONE file is the real one.)

CHECK 0:  You have <PC_IP> written down, and you know which file you
          flash to the board.

======================================================================
PART 1 - ESP32 SIDE (finish Stage 2)
======================================================================

1.1  Install the MQTT library.
     Arduino IDE > Tools > Manage Libraries > search "PubSubClient" >
     install the one by Nick O'Leary.
     (You should already have: Adafruit SHT31, Adafruit BusIO, BH1750.)

1.2  Edit the config at the top of the sketch:

        WIFI_SSID / WIFI_PASSWORD   - your Wi-Fi (replace the placeholders)
        MQTT_HOST = "<PC_IP>"       - the address from Part 0
        ROOM_ID   = "room-101"      - any short name for the room

1.3  Flash the board. Open Serial Monitor at 115200 baud.

1.4  You should see, within ~15 seconds:
        Wi-Fi: connected, IP 192.168.x.x
        MQTT: node id a1b2c3, topic base classroom/room-101/a1b2c3
        MQTT: connecting to <PC_IP>:1883... failed, rc=-2

     "failed" is EXPECTED right now - the broker does not exist yet.
     Everything else (Wi-Fi connected, node id printed) must be there.

CHECK 1:  Serial Monitor shows "Wi-Fi: connected" and an IP address,
          and the status panel prints every 2 seconds.

======================================================================
PART 2 - INSTALL DOCKER DESKTOP
======================================================================

Docker lets you run the broker, Node-RED, InfluxDB and Grafana as one
bundle instead of four separate installers. Strongly recommended.

2.1  Download "Docker Desktop for Windows":
        https://www.docker.com/products/docker-desktop/

2.2  Run the installer. Accept the WSL2 option if it asks. Reboot if
     told to.

2.3  Launch Docker Desktop. Wait until the whale icon in the system
     tray is steady (not animating). First start takes a few minutes.

2.4  Confirm it works - in PowerShell:
        docker run hello-world
     You should see "Hello from Docker!".

CHECK 2:  "docker run hello-world" prints the hello message.

     ---- No Docker? (fallback) ----
     You can install each service natively instead:
        Mosquitto : https://mosquitto.org/download/  (Windows installer)
        Node.js   : https://nodejs.org/  then:  npm install -g node-red
        InfluxDB 2: https://www.influxdata.com/downloads/ (Windows)
        Grafana   : https://grafana.com/grafana/download?platform=windows
     Then start each one and skip to Part 5. The rest of the guide
     still applies, only the "bring the stack up" step differs.

======================================================================
PART 3 - THE STACK FILES  (already created for you)
======================================================================

Two files are in this folder next to the guide:

  mosquitto.conf     - tells the broker to listen on port 1883 and
                       allow anonymous connections (fine for a LAN /
                       school project; add passwords before anything
                       real).

  docker-compose.yml - defines the four services and how they connect.
                       It also creates local folders for saved data so
                       nothing is lost when you restart.

You do not need to edit either one to get started. Open them in a text
editor if you want to see what they do.

======================================================================
PART 4 - BRING THE STACK UP
======================================================================

4.1  In PowerShell, go to this folder:

        cd "D:\Suvin's Project"

4.2  Start everything:

        docker compose up -d

     First run downloads the images (a few hundred MB). "-d" means it
     runs in the background.

4.3  Check all four are running:

        docker compose ps

     You want STATUS "Up" or "running" for: mosquitto, nodered,
     influxdb, grafana.

4.4  Web pages now available (open in a browser):
        Node-RED   http://localhost:1880
        InfluxDB   http://localhost:8086
        Grafana    http://localhost:3000   (login admin / admin)

     To STOP everything later:   docker compose down
     Your data survives a  down/up  cycle.

CHECK 4:  "docker compose ps" shows 4 services Up, and
          http://localhost:1880 loads the Node-RED editor.

======================================================================
PART 5 - CONFIRM THE ESP32 IS PUBLISHING  (MQTTX)
======================================================================

5.1  The broker is live now. Look at the ESP32 Serial Monitor - within
     5 seconds the line should change to:

        MQTT: connecting to <PC_IP>:1883... connected

     and the status panel's MQTT line becomes:

        | MQTT : connected, seq 12, time NOT synced

     ("time NOT synced" fixes itself within ~10 s once NTP responds.)

5.2  Install MQTTX (the desktop client):
        https://mqttx.app/  > Download for Windows

5.3  In MQTTX:  + New Connection
        Name:  local
        Host:  localhost      Port: 1883
        (leave username/password empty)
      Click Connect.

5.4  Add a subscription:  + New Subscription
        Topic:  classroom/#
      Click Confirm.

5.5  Every 2 seconds a message appears on
     classroom/room-101/<node>/telemetry  like:

        {"ts":1724835600,"ts_valid":true,"uptime_ms":40100,"seq":20,
         "temp_c":24.30,"hum_pct":46.70,"lux":420.0,
         "sound_avg_db":41.2,"sound_peak_db":58.6,
         "sound_calibrated":true,"alerts":"---","rssi":-43}

5.6  Test the Last Will: unplug the ESP32. After ~45 seconds a
     message  "offline"  appears on  .../status.  Plug it back in ->
     "online".

CHECK 5:  telemetry JSON arrives in MQTTX every 2 s, and ts_valid is
          true.  If not, see TROUBLESHOOTING at the bottom.

======================================================================
PART 6 - INFLUXDB: MAKE A PLACE TO STORE DATA
======================================================================

6.1  Open http://localhost:8086. First-time setup screen:
        Username:      <choose one>
        Password:      <choose one>
        Organization:  classroom
        Bucket:        sensors
      Click Continue / Save.

6.2  Create an API token for Node-RED to use:
        Load Data (left menu) > API Tokens > Generate API Token >
        "All Access API Token" (fine for a project) > name it
        "node-red" > Save.
      COPY the token string now - you cannot see it again later.
      Paste it somewhere safe.

(Keep the token in your password manager. Do not paste it into this file:
anything committed to git stays in the history even after deletion.)

CHECK 6:  You have: org = classroom, bucket = sensors, and a copied
          API token.

======================================================================
PART 7 - NODE-RED: CLEAN THE DATA AND STORE IT
======================================================================

Node-RED is a visual wiring tool. You drag "nodes" onto a canvas and
connect them. We build: MQTT in -> parse JSON -> sanity check ->
InfluxDB out.

7.1  Open http://localhost:1880.

7.2  Install the InfluxDB nodes:
        top-right menu (three bars) > Manage palette > Install tab >
        search "node-red-contrib-influxdb" > Install.

7.3  Build the flow. From the left palette, drag these onto the canvas
     left to right and wire them in a line (drag from the little grey
     port on the right of one node to the left port of the next):

     (a) "mqtt in" node.  Double-click it:
            Server: click the pencil > Server: mosquitto  Port: 1883
                    > Add / Update
            Topic:  classroom/+/+/telemetry
            Output: "a parsed JSON object"
            QoS: 0
         Done.

     (b) "function" node - name it "validate". Paste this code:

            const d = msg.payload;
            // drop anything not shaped like our telemetry
            if (typeof d !== 'object' || d.seq === undefined) return null;
            // range sanity - reject impossible readings
            const bad =
              (d.temp_c !== null && (d.temp_c < -10 || d.temp_c > 60)) ||
              (d.hum_pct !== null && (d.hum_pct < 0 || d.hum_pct > 100)) ||
              (d.lux !== null && (d.lux < 0 || d.lux > 120000)) ||
              (d.sound_peak_db < 0 || d.sound_peak_db > 140);
            if (bad) { node.warn('rejected: ' + JSON.stringify(d)); return null; }
            // split topic classroom/<room>/<node>/telemetry
            const parts = msg.topic.split('/');
            msg.room = parts[1];
            msg.node = parts[2];
            return msg;

     (c) "influxdb out" node.  Double-click it:
            Server: pencil >
                Version: 2.0
                URL: http://influxdb:8086
                Token: (paste the API token from Part 6)
                Organization: classroom
                Bucket: sensors
              > Add / Update
            Measurement: reading

     (d) OPTIONAL "debug" node wired off the "validate" output so you
         can watch messages in the right-hand Debug panel.

7.4  Click "Deploy" (top right).

7.5  Watch the Debug panel (bug icon, top right). Every 2 seconds a
     validated message should appear. The mqtt node should say
     "connected" under it.

CHECK 7:  Debug panel shows a telemetry object every 2 s and the
          InfluxDB node shows no error.

======================================================================
PART 8 - INFLUXDB: CONFIRM DATA IS LANDING
======================================================================

8.1  Open http://localhost:8086 > Data Explorer (graph icon, left).

8.2  Build a quick query:
        FROM: sensors
        Filter: _measurement = reading
        Filter: _field = temp_c
        > Submit
     You should see your temperature line, updating.

CHECK 8:  Data Explorer shows a temp_c series with recent points.

======================================================================
PART 9 - GRAFANA: THE DASHBOARD
======================================================================

9.1  Open http://localhost:3000 (admin / admin, set a new password).

9.2  Add InfluxDB as a data source:
        Connections > Data sources > Add data source > InfluxDB
          Query language: Flux
          URL: http://influxdb:8086
          Organization: classroom
          Token: (the same API token)
          Default bucket: sensors
        > Save & test  -> "datasource is working".

9.3  New dashboard > Add visualization > pick the InfluxDB source.
     Paste this Flux query for temperature:

        from(bucket: "sensors")
          |> range(start: -6h)
          |> filter(fn: (r) => r._measurement == "reading")
          |> filter(fn: (r) => r._field == "temp_c")

     You get a live temperature graph. Click "Apply".

9.4  Repeat "Add visualization" for hum_pct, lux, sound_peak_db -
     change the last filter line each time. Arrange the panels, Save
     the dashboard.

CHECK 9:  A Grafana dashboard shows temperature/humidity/lux/sound
          updating every few seconds.

  >>> At this point Stage 2 and the core of Stage 3-4 are DONE. <<<
      The rest is the parts that make it a real study, not a demo.

======================================================================
PART 10 - OCCUPANCY INPUT  (Stage 3, second data stream)
======================================================================

The readings only make sense against how full the room is. You want a
bucket: Unoccupied / Low / Medium / High - never an exact headcount
(privacy).

Simplest version to start:
  - In Node-RED add an "inject" node set to a string ("Low", "Medium",
    ...) and a second "influxdb out" writing measurement "occupancy".
    You manually inject the current level during a lesson.
  - Later, replace the manual inject with a real source (a PIR-based
    counter, a door sensor, timetable data) publishing to
    classroom/<room>/occupancy.

In Grafana, add the occupancy series as a second query on a panel, or
use it to split the sensor panels (group by occupancy level) so you
can compare "quiet room" vs "full room" conditions.

======================================================================
PART 11 - THE HUMAN FEEDBACK CHANNEL  (Stage 5)
======================================================================

Runs beside the sensors, not through them.

11.1  Make an anonymous form (Google Forms / Microsoft Forms):
        - "How comfortable is the room right now?" (1-5)
        - "Too hot / too cold / about right"
        - "Too bright / too dark / about right"
        - "Too noisy / about right"
        - "Is this monitor useful?" (yes/no + comment)
      No names, no email collection.

11.2  Collect responses to a spreadsheet. In the offline analysis
      stage you join these against the sensor data by timestamp and
      room, and check where the numbers and the perception agree or
      diverge (e.g. 24 C but people say "too cold").

======================================================================
PART 12 - OFFLINE ANALYSIS  (Stage 4, the report)
======================================================================

Export from InfluxDB (Data Explorer > CSV) or query it from a Python /
R notebook. Planned analyses:
  - descriptive stats per variable, per occupancy bucket
  - time-series: daily/weekly patterns, does a full room heat up
  - threshold-exceedance counts (how often over the noise limit, etc.)
  - before/after: pick an intervention (open a window on a schedule,
    change a light setting), compare the periods
  - sensor vs feedback: correlation / agreement between measured
    conditions and perceived comfort

======================================================================
TROUBLESHOOTING
======================================================================

ESP32 says "MQTT: ... failed, rc=-2"  (can't reach broker)
  - Wrong MQTT_HOST. Re-check <PC_IP> with ipconfig.
  - PC firewall blocking port 1883. Allow it:
      PowerShell (as Admin):
      New-NetFirewallRule -DisplayName "MQTT 1883" -Direction Inbound `
        -Protocol TCP -LocalPort 1883 -Action Allow
  - ESP32 and PC on different networks (guest Wi-Fi). Same SSID.
  - "docker compose ps" - is mosquitto actually Up?

ESP32 "rc=-4" or "rc=-2" intermittently
  - Broker up but slow / name clash. Usually harmless; it retries.

MQTTX connects but no messages
  - Wrong topic filter. Use exactly:  classroom/#
  - ESP32 Serial shows MQTT connected? If not, fix that first.

"time NOT synced" never clears
  - No internet on the PC/router, or UDP 123 blocked. NTP needs
    outbound UDP. Data still flows; ts stays 0 and ts_valid false.

Node-RED mqtt node stuck "connecting"
  - Server host must be  mosquitto  (the container name), NOT
    localhost, because Node-RED runs inside Docker. Port 1883.

InfluxDB node error "unauthorized"
  - Wrong token, or org/bucket name mismatch. Must be exactly
    classroom / sensors and the token from Part 6.

Grafana "datasource is working" but panels empty
  - range too short, or field name typo. Confirm data in InfluxDB
    Data Explorer first (Part 8).

Everything was working, now nothing after a reboot
  - Start Docker Desktop, then:  cd "D:\Suvin's Project"; docker compose up -d
  - Re-flash / power-cycle the ESP32.

Ports already in use (1880/8086/3000/1883)
  - Something else is using them. Stop it, or edit the left-hand port
    numbers in docker-compose.yml (e.g. "3001:3000") and use the new
    number in the browser.

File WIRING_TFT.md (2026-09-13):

# Wiring: 3.5" ILI9481 shield -> ESP32-S3 DevKitC-1 N16R8

Shield labels are read straight off its silkscreen (headers J1-J4).
ESP32 pins are the GPIO numbers printed on the DevKitC-1 silkscreen.

Both boards have MALE pins, so you need **female-to-female** jumpers.

## Required: the display (13 signals + power)

| Shield header | Label | (Uno pin) | -> ESP32-S3 |
|---|---|---|---|
| J1 | LCD_D0 | D8 | **10** |
| J1 | LCD_D1 | D9 | **11** |
| J2 | LCD_D2 | D2 | **12** |
| J2 | LCD_D3 | D3 | **13** |
| J2 | LCD_D4 | D4 | **14** |
| J2 | LCD_D5 | D5 | **15** |
| J2 | LCD_D6 | D6 | **16** |
| J2 | LCD_D7 | D7 | **17** |
| J3 | LCD_RD | A0 | **39** |
| J3 | LCD_WR | A1 | **38** |
| J3 | LCD_RS | A2 | **2** |
| J3 | LCD_CS | A3 | **1** |
| J3 | LCD_RST  | A4 | **42** |
| J4 | 5V | 5V | **5V** |
| J4 | 3.3V | 3.3V | **3V3**  (REQUIRED - no onboard regulator) |
| J4 | GND | GND | **GND** |
| J4 | GND | GND | **GND** (2nd, recommended) |

LCD_RS and LCD_CS go to GPIO 2 and 1 specifically: they double as the
touch panel's XM/YP and get analogRead(), so they must be ADC1 (GPIO1-10).
ADC2 stops working when Wi-Fi is on - the same constraint that pins the
mic to GPIO5.

## Leave unconnected

| Shield pin | Why |
|---|-----|
| J3 `F_CS` | chip-select for the W25Q32 flash footprint, which is bare |
| J4 `RESET` | do not let the shield pull the ESP32 reset line |
| J1 top 2 (unlabelled) | Uno AREF / GND |
| J2 bottom 2 (unlabelled) | Uno D0/D1 = RX/TX |
| J4 `VIN`, `IOREF` | not used |

## Optional: the microSD slot (J1)

Only if you want the node to buffer readings while MQTT is down.

| Label | (Uno pin) | -> ESP32-S3 |
|---|---|---|
| SD_SCK | D13 | **18** |
| SD_DO (MISO)  | D12 | **21** |
| SD_DI (MOSI)  | D11 | **47** |
| SD_SS | D10 | **41** |

## Already in use - do not disturb

| GPIO | Function |
|---|---|
| 5 | MAX4466 mic (ADC1) |
| 7 | buzzer |
| 8/9  | I2C SDA/SCL - SHT3x + BH1750 |
| 43/44| UART0, the Serial CSV output |

## Regulator test - RESOLVED 2026-09-13: this board has NO regulator

1. Wire **5V and GND only**. Nothing else.
2. Power the ESP32 over USB.
3. Measure the shield's `3.3V` pin against GND.

- **~3.3 V** -> onboard regulator present. Leave `3.3V` unconnected. Done.
- **0 V** -> no regulator. Also wire shield `3.3V` -> ESP32 `3V3`.

**Result on this board: no regulator.** A visual check found no AMS1117 or
any other 3.3 V part - only U1/U2, both marked `SM245TC` (octal bus
transceivers). So J4 `3.3V` is an INPUT and must be wired, and the whole
shield logic domain sits at 3.3 V: the 245 buffers run off that rail, not
off 5 V. Symptom while it was unwired: backlight lit (it runs from 5 V),
screen permanently white, ID readback 0x00/0xFF - the controller and its
buffers had no logic supply at all.

Because the buffers run at 3.3 V, the `HC245` input-threshold concern
below does not apply to this board - the ESP32's 3.3 V drive is correct
by construction.

While you have it open, read the markings on U1/U2 (the two SOIC bus
buffers). `LVC245` or `ALC245` is fine driven from 3.3V logic. A plain
`HC245` running off 5V has a ~3.5 V input threshold, and the S3's 3.3 V
drive would be marginal - stop and reconsider if that is what is fitted.

## Wiring notes

- Keep the 8 data wires and especially `LCD_WR` short and similar length.
  It is a parallel bus; long floppy jumpers on WR cause glitchy pixels.
- Connect both GNDs if you can. 13 fast-switching lines need a return path.
- Backlight pulls ~120-150 mA. Fine over USB; leave headroom when you
  move to a wall adapter.

## Smoke test

Before flashing the full sketch, confirm the bus:

```cpp
#include <TFT_eSPI.h>
TFT_eSPI tft = TFT_eSPI();
void setup() { tft.init(); tft.setRotation(1); tft.fillScreen(TFT_RED); }
void loop() {}
```

Red screen = bus and pin map are correct. Then flash `CR_Monitor.ino`.

White/blank = check LCD_WR, LCD_CS, LCD_RST and the 3.3V question first.

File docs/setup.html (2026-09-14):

Classroom Environment Monitor ESP32-S3 · rev 2026-09-13

On this page

Prerequisites Toolchain Credentials TFT_eSPI pin map Bring-up order Flash the node Calibrate the mic Start the stack Verify the stream InfluxDB Node-RED Grafana Before real use

Build & bring-up

# From an empty board to a live dashboard

Budget two to three hours the first time, most of it waiting on downloads. The order here is not arbitrary. Each stage ends with something you can check, and a check that fails tells you which stage broke rather than leaving you with a dead board and five suspects.

## Prerequisites

Three things to have before starting.

- Your PC's LAN address. Run ipconfig on Windows or ip addr on Linux and note the IPv4 address on your local network. The node needs this to find the broker, and localhost will not do: the node is a separate machine.
- The ESP32 wired. All sensors and, if you are using it, the display. See pins and wiring.
- A phone SPL meter app. Needed for the microphone calibration, which cannot be skipped if you want the sound alarm to work.

## Toolchain

### Install the Arduino IDE and the ESP32 board package

1. Then set the board and its options exactly as below. The PSRAM setting in particular is not the default.

Setting | Value
Board | ESP32S3 Dev Module
PSRAM | OPI PSRAM
Flash Size | 16MB

### Install four libraries

2. All from the Library Manager. The first pulls in a dependency you should accept.

Library | Author | For
Adafruit SHT31 | Adafruit | Temperature and humidity. Also installs Adafruit BusIO.
BH1750 | Christopher Laws | Illuminance.
PubSubClient | Nick O'Leary | MQTT.
TFT_eSPI | Bodmer | The display. Needs the extra configuration step below.

### Install Docker Desktop

3. Needed for the backend, not for the node. If Docker Desktop will not run on your machine, the four services can be installed natively instead, at the cost of doing four installs and four config files by hand.

## Credentials

Wi-Fi and broker credentials live in secrets.h, which is gitignored and not in the repository. Create it from the template.

cd CR_Monitor
cp secrets.example.h secrets.h

Then fill in the real values.

const char* WIFI_SSID     = "YOUR_WIFI_SSID";
const char* WIFI_PASSWORD = "YOUR_WIFI_PASSWORD";

// Leave both empty for an anonymous broker.
const char* MQTT_USER = "";
const char* MQTT_PASS = "";

Two more values live in CR_Monitor.ino itself and need editing per install:

const char* MQTT_HOST = "192.168.1.5";   // your PC's LAN IP
const char* ROOM_ID   = "room-101";      // this node's room

#### Which file is the real sketch

CR_Monitor/CR_Monitor.ino. A copy exists at the repository root as CR_Monitor.cpp; it is a working duplicate, it is gitignored, and it is behind. Older notes in SETUP_GUIDE.txt describe the opposite arrangement and are stale. Open the .ino.

## TFT_eSPI pin map

#### This is the step that most often gets skipped

TFT_eSPI does not read its configuration from your sketch folder. It reads it from inside its own installed library directory. The pin map is versioned in this repository so it is not lost, but a copy in the repo has no effect on a build: you have to install it. Miss this and the display will not work no matter how correct your wiring is.

Pick either approach.

- Copy the body of CR_Monitor/TFT_Setup_CR_Monitor.h over TFT_eSPI/User_Setup.h in your Arduino libraries folder, or
- place the file in the TFT_eSPI folder and point User_Setup_Select.h at it.

The file selects the driver as well as the pins. Exactly one driver may be active, and it is set to ILI9481_DRIVER, confirmed against this panel on 2026-09-13.

#### If the screen is white but the backlight is lit

A wrong driver produces exactly this: the init sequence means nothing to the controller, so nothing is ever drawn. It is also what a missing 3.3 V logic supply looks like, so rule out the regulator question first. Then work down the commented driver list in the setup header, reflashing each time. This panel was assumed to be HX8357D for a while, which is why it stayed white; the pin map had been right the whole time.

## Bring-up order

Five single-purpose sketches, each proving one thing. Run them in this order on a board you have not run before. Each takes under a minute and saves considerably more than that.

Sketch | Proves | Pass looks like
Test_Rail | Supply rails are where they should be. | Measured millivolts within tolerance.
I2C_Scan | The bus works and devices acknowledge. | 0x44 and 0x23 found
Test_SHT3x | Temperature and humidity read plausibly. | Room temperature, stable.
Test_BH1750 | Illuminance responds to light. | Value drops when you cover the sensor.
Test_TFT | The parallel bus and pin map are correct. | A solid red screen.

If I2C_Scan finds nothing, check SDA on GPIO8, SCL on GPIO9, that 3.3 V is actually present at the sensors, and that they share a ground with the ESP32. That combination accounts for nearly every empty scan.

## Flash the node

### Open and upload CR_Monitor.ino

1. Then open Serial Monitor at 115200 baud.

### Read the self-test

2. The boot report runs before anything else and tells you what the node thinks of its own hardware. Two beeps at the end are the buzzer self-test. Do not move on with a FAIL on the bus or the microphone.

### Confirm the panel and the CSV

3. A boxed status block and a CSV row should appear every two seconds, and the TFT should show four cards with live values.

+------------------------------+
| Classroom Monitor
| Temp : 23.7 C
| Humid: 58.2 %
| Light: 412 lx
| Sound: 52 dB peak (avg 44 dB, 1.31 mVrms)
| Wi-Fi: connected
| MQTT : connected, seq 20, time ok
+------------------------------+

## Calibrate the microphone

Do this before trusting any decibel figure, and before the sound alarm will arm at all. The node ships with sound_calibrated reporting whether this has been done.

First check the raw statistics printed by SOUND_DEBUG. In a quiet room the mean should be around 1900 to 2100 counts with a peak-to-peak of a few tens. A drifting mean with large random swings means a floating pin, not a loud room.

Then follow the four-step procedure on the firmware page: zero the constant, read the panel, measure the room with a real meter, and set the constant to the difference. Verify at the loud end afterwards, because an error that only appears when loud is the amplifier clipping and needs the trimpot turned down instead.

## Start the stack

docker compose up -d

Four services come up. Data lives in named volumes, so docker compose down keeps it.

Service | Image | URL | Role
mosquitto | eclipse-mosquitto:2 | :1883 | Broker. Everything the node says arrives here.
nodered | nodered/node-red | :1880 | Subscribes, validates, writes.
influxdb | influxdb:2.7 | :8086 | Time-series storage.
grafana | grafana/grafana | :3000 | Dashboards. First login is admin / admin.

docker compose logs -f mosquitto     # watch the broker
docker compose ps                    # confirm all four are up

#### Inside the stack, use container names and not localhost

Node-RED talks to InfluxDB at http://influxdb:8086 and to the broker at host mosquitto. From inside a container, localhost means that container itself, so a connection to localhost:8086 goes nowhere. Use localhost only in your own browser.

## Verify the stream

Before building anything downstream, confirm messages are actually arriving. Install MQTTX, connect it to your PC's LAN IP on port 1883, and subscribe to:

classroom/#

You should see a telemetry object every two seconds, plus a retained status of online that arrives the moment you subscribe. If telemetry is flowing but nothing reaches Node-RED later, the problem is downstream of here, which is worth knowing now.

## InfluxDB

### Complete initial setup

1. Open http://localhost:8086 and work through the first-run wizard. Set the organisation to classroom and the initial bucket to sensors. These names are referenced by both Node-RED and Grafana.

### Create an API token

2. Generate a token with write access to the sensors bucket. Copy it somewhere outside the repository; you will paste it into Node-RED and Grafana, and it is shown in full only once.

#### Do not paste the token into a tracked file

Not into a sketch, not into a notes file, not into a setup guide. Anything committed to git stays in the history even after you delete it, and a repository that is private today may not be tomorrow. Keep tokens in the tools that need them. If one does end up committed, revoking and reissuing it in InfluxDB is the fix; deleting the line is not.

## Node-RED

Three nodes in a line, plus an optional debug tap. This is where raw MQTT becomes rows in a database, and where impossible readings get rejected.

### Install the InfluxDB nodes

1. Menu, then Manage palette, Install tab, search node-red-contrib-influxdb, install.

### Add an mqtt in node

Server | mosquitto
Port | 1883
Topic | classroom/+/+/telemetry
Output | a parsed JSON object
QoS | 0

### Add a function node named validate

3. It does two jobs: drop anything not shaped like this project's telemetry, and reject physically impossible values so one bad reading does not end up in a chart forever.

const d = msg.payload;
// drop anything not shaped like our telemetry
if (typeof d !== 'object' || d.seq === undefined) return null;

// range sanity - reject impossible readings
const bad =
  (d.temp_c  !== null && (d.temp_c  < -10 || d.temp_c  > 60)) ||
  (d.hum_pct !== null && (d.hum_pct < 0   || d.hum_pct > 100)) ||
  (d.lux     !== null && (d.lux     < 0   || d.lux     > 120000)) ||
  (d.sound_peak_db < 0 || d.sound_peak_db > 140);
if (bad) { node.warn('rejected: ' + JSON.stringify(d)); return null; }

// split topic classroom/<room>/<node>/telemetry
const parts = msg.topic.split('/');
msg.room = parts[1];
msg.node = parts[2];
return msg;
  Note that each numeric check is guarded against null first. A failed sensor read publishes null, and comparing null against a number would silently reject a perfectly good message.

### Add an influxdb out node

Version | 2.0
URL | http://influxdb:8086
Token | the token from the previous section
Organization | classroom
Bucket | sensors
Measurement | reading

### Deploy and watch

5. Wire a debug node off the validate output. After deploying, a validated object should appear in the Debug panel every two seconds, the mqtt node should read connected, and the InfluxDB node should show no error.

Confirm the data landed before moving on. In the InfluxDB Data Explorer, query bucket sensors, filter _measurement = reading and _field = temp_c, and you should see a live line.

## Grafana

### Add InfluxDB as a data source

1. Open http://localhost:3000, sign in with admin / admin, set a new password, then Connections, Data sources, Add data source, InfluxDB.

Query language | Flux
URL | http://influxdb:8086
Organization | classroom
Token | the same token
Default bucket | sensors

  Save and test should report that the datasource is working.

### Build the first panel

2. New dashboard, add visualization, pick the InfluxDB source, and paste this Flux query.

from(bucket: "sensors")
  |> range(start: -6h)
  |> filter(fn: (r) => r._measurement == "reading")
  |> filter(fn: (r) => r._field == "temp_c")

### Repeat for the other three series

3. Change the final filter to hum_pct, lux and sound_peak_db in turn. Arrange the panels and save the dashboard.

#### At this point the pipeline is complete

Sensors to broker to validation to storage to dashboard, updating every two seconds. What remains is what turns a working demo into an actual study: the occupancy stream, the comfort responses, and the analysis that puts the two against the sensor data.

## Before real use

The defaults here are chosen for getting a bench build working, and several of them are wrong for a building with people in it. None is hard to fix; they just have to be done deliberately.

Default | Risk | Fix
allow_anonymous true | Anyone on the LAN can read all telemetry or inject convincing fake readings. | A Mosquitto password file, per-node credentials, and topic ACLs limiting each node to its own subtree.
admin / admin | Grafana ships with a known password. | Change it at first login, which Grafana prompts for. Do not skip the prompt.
port 1883 | Credentials and payloads cross the network in plain text. | TLS on 8883 once authentication is in place.
all-access API token | A single token with full organisation rights in two config fields. | Separate tokens: write-only to sensors for Node-RED, read-only for Grafana.
thresholds in firmware | Placeholder limits presented as if they were standards. | Cite a source for each band before publishing any findings from the data.

One thing that is already right and worth keeping right: the sound path never records audio, and the planned occupancy input is a bucket rather than a headcount. Those are the properties that make the monitor something a room full of people can reasonably be asked to accept, and they are easy to erode by accident once someone wants better data.

Pins & wiringEvery connection, with the reasoning FirmwareWhat runs on the node once it is flashed MQTT contractThe payload schema Node-RED consumes

Classroom Environment Monitor · bring-up guide for the 2026-09-13 revision

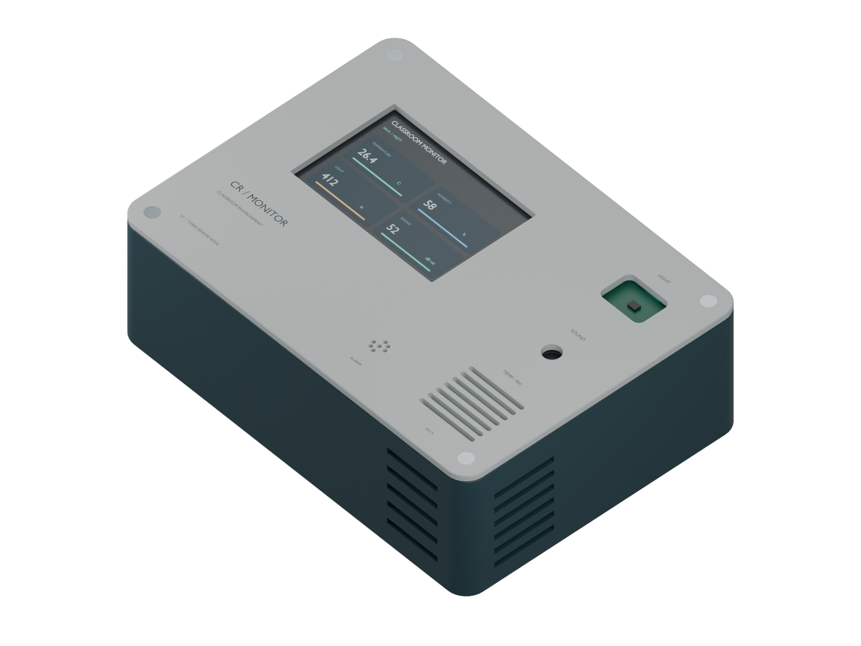
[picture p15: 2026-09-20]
CR_Monitor_Enclosure/previews/01_assembled.png

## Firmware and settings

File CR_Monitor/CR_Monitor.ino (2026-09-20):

/* Classroom Environment Monitor - Stage 2 (real hardware)
 * ESP32-S3 DevKitC-1. Full design notes: CR_Monitor_NOTES.txt
 *
 * Sensors : SHT3x (temp/humidity), BH1750 (lux), MAX4466 (sound)
 * Outputs : buzzer, Serial (CSV + status panel), MQTT JSON telemetry
 * Libs    : Adafruit SHT31 (+ Adafruit BusIO), BH1750, PubSubClient
 */

 #include <Wire.h>
 #include <WiFi.h>
 #include <time.h>
 #include "secrets.h"      // untracked credentials
 #include <esp_mac.h>
 #include <PubSubClient.h>
 #include <Adafruit_SHT31.h>
 #include <BH1750.h>

 // ============================ PINS ============================
 #define I2C_SDA     8
 #define I2C_SCL     9
 #define MIC_PIN     5      // must be an ADC1 pin (ADC2 fails with Wi-Fi on)
 #define BUZZER_PIN  7

 #define SHT3X_ADDR   0x44  // 0x45 if ADDR pin high
 #define BH1750_ADDR  0x23  // 0x5C if ADDR pin high

 // ============================ WI-FI ===========================
 // SSID and password live in secrets.h - see secrets.example.h

 const unsigned long WIFI_CONNECT_TIMEOUT_MS = 15000;
 const unsigned long WIFI_RETRY_DELAY_MS     = 5000;

 // ============================ MQTT ============================
 // Topics: classroom/<room>/<node>/{telemetry,status,alert}
 const char*    MQTT_HOST      = "192.168.1.8";   // <-- broker LAN IP
 const uint16_t MQTT_PORT      = 1883;
 // MQTT_USER / MQTT_PASS live in secrets.h
 const char*    ROOM_ID        = "room-101";       // <-- set per room

 const unsigned long MQTT_RECONNECT_MS = 5000;
 const uint16_t      MQTT_KEEPALIVE_S  = 30;

 // ============================ TIME (NTP) ======================
 const char*  NTP_SERVER     = "pool.ntp.org";
 const long   GMT_OFFSET_SEC = 0;                  // store UTC
 const int    DST_OFFSET_SEC = 0;
 // Telemetry stays in UTC (GMT_OFFSET_SEC above) so stored data is
 // unambiguous across sites. This offset is applied to the PANEL CLOCK
 // only - changing GMT_OFFSET_SEC instead would silently retimestamp
 // every MQTT message.
 const long   DISPLAY_TZ_OFFSET_SEC = 8 * 3600;   // UTC+8, panel clock only
 const time_t TIME_VALID_MIN = 1700000000;         // clock is synced if past this

 // ============================ THRESHOLDS ======================
 // Placeholder limits - justify against a cited standard before collecting data.
 const float TEMP_MAX_C   = 30.0;
 const float TEMP_MIN_C   = 18.0;
 const float LUX_MIN      = 300.0;
 const float LUX_MAX      = 800.0;
 const float SOUND_MAX_DB = 70.0;

 // Hysteresis: how far back inside the band a reading must return before
 // the alarm clears (stops chatter on the line).
 const float TEMP_HYST  = 0.5;
 const float LUX_HYST   = 25.0;
 const float SOUND_HYST = 3.0;

 // ============================ SOUND ===========================
 // Relative level, NOT a calibrated SPL meter. See CR_Monitor_NOTES.txt
 // for the model and the MIC_CAL_DB calibration procedure.
 //   dB = 20*log10(Vrms / MIC_REF_V) + MIC_DB_OFFSET + MIC_CAL_DB
 const float    ADC_MAX       = 4095.0f;
 const float    ADC_VREF      = 3.3f;
 const float    MIC_REF_V     = 0.00631f;
 const float    MIC_DB_OFFSET = 94.0f;
 const float    MIC_CAL_DB    = -77.0f;    // from calibration 2026-08-28

 float          micBias       = ADC_MAX / 2.0f;  // DC offset, measured at boot
 float          soundRmsMv    = 0;                // last reading, for calibration

 const uint16_t MIC_WINDOW_MS = 100;
 float soundAvgDb = 0;
 float soundMaxDb = 0;

 #define SOUND_DEBUG  true   // print raw ADC stats each read (wiring sanity check)

 const unsigned long READ_INTERVAL_MS = 2000;

 // ============================ OBJECTS / STATE =================
 Adafruit_SHT31    sht3x = Adafruit_SHT31();
 BH1750            lightMeter(BH1750_ADDR);

 WiFiClient        netClient;
 PubSubClient      mqtt(netClient);

 String   nodeId;
 String   topicTelemetry, topicStatus, topicAlert;
 unsigned long mqttLastTry  = 0;
 uint32_t      mqttFails    = 0;
 uint32_t      seq          = 0;
 int           lastAlertMask = -1;

 bool timeValid() { return time(nullptr) > TIME_VALID_MIN; }

 bool shtReady    = false;
 bool bh1750Ready = false;

 unsigned long lastRead   = 0;
 uint32_t      shtFails   = 0;
 uint32_t      luxFails   = 0;

 bool alertTemp  = false;
 bool alertLight = false;
 bool alertSound = false;

 // ============================ BUZZER =========================
 // Non-blocking beeper - no delay() anywhere in the pattern.
 const uint16_t BEEP_ON_MS  = 150;
 const uint16_t BEEP_OFF_MS = 150;
 const uint16_t FREQ_TEMP  = 2200;   // 3 beeps
 const uint16_t FREQ_LIGHT = 1200;   // 2 beeps
 const uint16_t FREQ_SOUND = 1700;   // 4 beeps

 uint8_t       beepsLeft = 0;
 bool          beepOn    = false;
 uint16_t      beepFreq  = 2000;
 unsigned long beepNext  = 0;

 void startAlarm(uint8_t beeps, uint16_t freq) {
   if (beepsLeft > 0) return;          // let the current pattern finish
   beepsLeft = beeps * 2;
   beepFreq  = freq;
   beepOn    = false;
   beepNext  = 0;
 }

 void serviceAlarm() {
   if (beepsLeft == 0) return;
   if (millis() < beepNext) return;

   beepOn = !beepOn;
   if (beepOn) {
     tone(BUZZER_PIN, beepFreq);
     beepNext = millis() + BEEP_ON_MS;
   } else {
     noTone(BUZZER_PIN);
     beepNext = millis() + BEEP_OFF_MS;
   }
   beepsLeft--;
   if (beepsLeft == 0) noTone(BUZZER_PIN);
 }

 // ============================ HELPERS ========================

 void i2cScan() {
   Serial.println(F("--- I2C scan ---"));
   uint8_t found = 0;
   for (uint8_t addr = 1; addr < 127; addr++) {
     Wire.beginTransmission(addr);
     if (Wire.endTransmission() == 0) {
       Serial.printf("  device at 0x%02X", addr);
       if      (addr == 0x44 || addr == 0x45) Serial.print(F("  <- SHT3x"));
       else if (addr == 0x23 || addr == 0x5C) Serial.print(F("  <- BH1750"));
       else if (addr == 0x27 || addr == 0x3F) Serial.print(F("  <- LCD backpack (unused)"));
       Serial.println();
       found++;
     }
   }
   if (found == 0) {
     Serial.println(F("  nothing found."));
     Serial.println(F("  check: SDA=GPIO8 SCL=GPIO9, 3.3V present, common ground"));
   }
   Serial.println(F("----------------"));
 }

 // Measure the MAX4466 DC operating point once at boot. Keep the room quiet.
 void calibrateMicBias() {
   const uint16_t N = 2000;
   float sum = 0;
   for (uint16_t i = 0; i < N; i++) { sum += analogRead(MIC_PIN); delayMicroseconds(200); }
   micBias = sum / N;
 }

 static float countsToDb(float rmsCounts) {
   float vrms = (rmsCounts * ADC_VREF) / ADC_MAX;
   if (vrms < 1e-6f) vrms = 1e-6f;              // avoid log10(0)
   return 20.0f * log10f(vrms / MIC_REF_V) + MIC_DB_OFFSET + MIC_CAL_DB;
 }

 // Fills soundAvgDb / soundMaxDb from RMS sub-windows (DC bias removed).
 void readSound() {
   const uint16_t SUB_MS    = 10;
   const uint8_t  SUB_COUNT = MIC_WINDOW_MS / SUB_MS;

   float sumDb    = 0;
   float maxDb    = -200.0f;
   float sumSqAll = 0;
   uint32_t nAll  = 0;
   int rawMin = 4095, rawMax = 0;
   double rawSum = 0;

   for (uint8_t s = 0; s < SUB_COUNT; s++) {
     unsigned long start = millis();
     float  sumSq = 0;
     uint32_t n   = 0;

     while (millis() - start < SUB_MS) {
       int raw = analogRead(MIC_PIN);
       if (raw <= 0 || raw >= 4095) continue;   // drop ESP32 ADC rail glitches
       if (raw < rawMin) rawMin = raw;
       if (raw > rawMax) rawMax = raw;
       rawSum += raw;

       float ac = raw - micBias;
       sumSq += ac * ac;
       n++;
     }
     if (n == 0) continue;

     float rmsCounts = sqrtf(sumSq / n);
     float db        = countsToDb(rmsCounts);
     sumDb += db;
     if (db > maxDb) maxDb = db;

     sumSqAll += sumSq;
     nAll     += n;
   }

   soundAvgDb = sumDb / SUB_COUNT;
   soundMaxDb = maxDb;
   soundRmsMv = nAll ? (sqrtf(sumSqAll / nAll) * ADC_VREF / ADC_MAX) * 1000.0f : 0.0f;

   if (SOUND_DEBUG && nAll) {
     Serial.printf("# mic raw: mean=%.0f min=%d max=%d p-p=%d  (bias=%.0f)\n",
                   rawSum / nAll, rawMin, rawMax, rawMax - rawMin, micBias);
   }
 }

 // Returns lux, or -1.0 on failure.
 float readLux() {
   if (!bh1750Ready) return -1.0f;
   float lux = lightMeter.readLightLevel();
   return (lux < 0) ? -1.0f : lux;
 }

 void evaluateAlarms(bool tempOk, float temp, bool luxOk, float lux, float soundPeak) {
   if (tempOk) {
     bool breach = alertTemp
       ? (temp > TEMP_MAX_C - TEMP_HYST || temp < TEMP_MIN_C + TEMP_HYST)
       : (temp > TEMP_MAX_C || temp < TEMP_MIN_C);
     if (breach && !alertTemp) {
       Serial.print(F("# ALERT temperature: ")); Serial.println(temp, 2);
       startAlarm(3, FREQ_TEMP);
     } else if (!breach && alertTemp) {
       Serial.println(F("# CLEAR temperature"));
     }
     alertTemp = breach;
   }

   if (luxOk) {
     bool breach = alertLight
       ? (lux < LUX_MIN + LUX_HYST || lux > LUX_MAX - LUX_HYST)
       : (lux < LUX_MIN || lux > LUX_MAX);
     if (breach && !alertLight) {
       Serial.print(F("# ALERT light: ")); Serial.println(lux, 0);
       startAlarm(2, FREQ_LIGHT);
     } else if (!breach && alertLight) {
       Serial.println(F("# CLEAR light"));
     }
     alertLight = breach;
   }

   // Sound alarm only fires once MIC_CAL_DB is set (an uncalibrated dB
   // figure is tens of dB off and would alarm constantly). Still logs.
   if (MIC_CAL_DB != 0.0f) {
     bool breach = alertSound
       ? (soundPeak > SOUND_MAX_DB - SOUND_HYST)
       : (soundPeak > SOUND_MAX_DB);
     if (breach && !alertSound) {
       Serial.print(F("# ALERT sound: ")); Serial.println(soundPeak, 1);
       startAlarm(4, FREQ_SOUND);
     } else if (!breach && alertSound) {
       Serial.println(F("# CLEAR sound"));
     }
     alertSound = breach;
   }
 }

 String alarmBanner() {
   if (!alertTemp && !alertLight && !alertSound) return "Classroom Monitor";
   String s = "ALERT:";
   if (alertTemp)  s += " TMP";
   if (alertLight) s += " LGT";
   if (alertSound) s += " SND";
   return s;
 }

 // Readable status block on Serial (replaces the dead LCD).
 void printPanel(bool tempOk, float temp, float hum,
                 bool luxOk, float lux, bool wifiUp) {
   Serial.println(F("+------------------------------+"));
   Serial.print  (F("| ")); Serial.println(alarmBanner());

   if (tempOk) {
     Serial.print(F("| Temp : ")); Serial.print(temp, 1); Serial.println(F(" C"));
     Serial.print(F("| Humid: ")); Serial.print(hum, 1);  Serial.println(F(" %"));
   } else {
     Serial.println(F("| Temp : --.- C  ERR"));
     Serial.println(F("| Humid: --.- %"));
   }

   Serial.print(F("| Light: "));
   if (luxOk) { Serial.print((int)lux); Serial.println(F(" lx")); }
   else       { Serial.println(F("---- lx")); }

   Serial.print(F("| Sound: ")); Serial.print(soundMaxDb, 0);
   Serial.print(F(" dB peak (avg "));  Serial.print(soundAvgDb, 0);
   Serial.print(F(" dB, "));           Serial.print(soundRmsMv, 2);
   Serial.println(F(" mVrms)"));

   Serial.print(F("| Wi-Fi: "));
   Serial.println(wifiUp ? F("connected") : F("DOWN"));

   Serial.print(F("| MQTT : "));
   if      (!wifiUp)          Serial.println(F("- (no Wi-Fi)"));
   else if (mqtt.connected()) Serial.print(F("connected"));
   else                       Serial.println(F("down"));
   if (wifiUp && mqtt.connected()) {
     Serial.print(F(", seq ")); Serial.print(seq);
     Serial.println(timeValid() ? F(", time ok") : F(", time NOT synced"));
   }
   Serial.println(F("+------------------------------+"));
 }

 // Screen version of the block above. Included here, not at the top of the
 // file, because it reads globals declared further up (soundMaxDb, mqtt,
 // seq, alertTemp/Light/Sound).
 #include "TFT_Panel.h"

 // Boot self-test. After TFT_Panel.h so it can read the panel back.
 #include "Preflight.h"

 // ============================ WI-FI STATE MACHINE =============
 // SCAN -> CONNECTING -> CONNECTED, falling back to WAIT_RETRY on any
 // failure or link drop. Sensors and buzzer run regardless of network.
 enum WifiState { WIFI_ST_SCAN, WIFI_ST_CONNECTING, WIFI_ST_CONNECTED, WIFI_ST_WAIT_RETRY };
 WifiState     wifiState      = WIFI_ST_SCAN;
 unsigned long wifiStateSince = 0;
 uint32_t      wifiRetryCount = 0;

 bool wifiSsidInRange(const char* ssid) {
   int found = WiFi.scanNetworks();
   bool inRange = false;
   for (int i = 0; i < found; i++) {
     if (WiFi.SSID(i) == ssid) { inRange = true; break; }
   }
   WiFi.scanDelete();
   return inRange;
 }

 void handleWifi() {
   switch (wifiState) {

     case WIFI_ST_SCAN:
       Serial.print(F("Wi-Fi: scanning for \"")); Serial.print(WIFI_SSID);
       Serial.println(F("\"..."));
       if (wifiSsidInRange(WIFI_SSID)) {
         Serial.println(F("Wi-Fi: found, connecting..."));
         WiFi.begin(WIFI_SSID, WIFI_PASSWORD);
         wifiState      = WIFI_ST_CONNECTING;
         wifiStateSince = millis();
       } else {
         Serial.println(F("Wi-Fi: not in range, will retry"));
         wifiState      = WIFI_ST_WAIT_RETRY;
         wifiStateSince = millis();
       }
       break;

     case WIFI_ST_CONNECTING:
       if (WiFi.status() == WL_CONNECTED) {
         Serial.print(F("Wi-Fi: connected, IP "));
         Serial.print(WiFi.localIP());
         Serial.print(F(", RSSI "));
         Serial.println(WiFi.RSSI());
         wifiRetryCount = 0;
         wifiState      = WIFI_ST_CONNECTED;
       } else if (millis() - wifiStateSince > WIFI_CONNECT_TIMEOUT_MS) {
         wifiRetryCount++;
         Serial.print(F("Wi-Fi: timed out, retry #")); Serial.println(wifiRetryCount);
         WiFi.disconnect(true);
         wifiState      = WIFI_ST_WAIT_RETRY;
         wifiStateSince = millis();
       }
       break;

     case WIFI_ST_CONNECTED:
       if (WiFi.status() != WL_CONNECTED) {
         Serial.println(F("Wi-Fi: lost, reconnecting"));
         wifiState      = WIFI_ST_WAIT_RETRY;
         wifiStateSince = millis();
       }
       break;

     case WIFI_ST_WAIT_RETRY:
       if (millis() - wifiStateSince > WIFI_RETRY_DELAY_MS) wifiState = WIFI_ST_SCAN;
       break;
   }
 }

 // ============================ MQTT ===========================
 // Runs downstream of Wi-Fi; never blocks more than the socket timeout.

 void mqttInit() {
   // Read the MAC from eFuse, not from the Wi-Fi driver. WiFi.macAddress()
   // returns all zeros until the driver has actually started, which gave
   // every node the id "000000" - a shared MQTT client id makes brokers
   // disconnect each node as the next one connects.
   uint8_t mac[6];
   esp_read_mac(mac, ESP_MAC_WIFI_STA);
   char id[7];
   snprintf(id, sizeof(id), "%02x%02x%02x", mac[3], mac[4], mac[5]);
   nodeId = id;

   String base    = String("classroom/") + ROOM_ID + "/" + nodeId + "/";
   topicTelemetry = base + "telemetry";
   topicStatus    = base + "status";
   topicAlert     = base + "alert";

   mqtt.setServer(MQTT_HOST, MQTT_PORT);
   mqtt.setKeepAlive(MQTT_KEEPALIVE_S);
   mqtt.setSocketTimeout(3);
   mqtt.setBufferSize(512);

   Serial.print(F("MQTT: node id ")); Serial.print(nodeId);
   Serial.print(F(", topic base classroom/")); Serial.print(ROOM_ID);
   Serial.print('/'); Serial.println(nodeId);
 }

 void mqttConnect() {
   const char* user = strlen(MQTT_USER) ? MQTT_USER : nullptr;
   const char* pass = strlen(MQTT_PASS) ? MQTT_PASS : nullptr;

   Serial.print(F("MQTT: connecting to "));
   Serial.print(MQTT_HOST); Serial.print(':'); Serial.print(MQTT_PORT); Serial.print(F("... "));

   // Last Will -> broker publishes "offline" (retained) if this node drops.
   bool ok = mqtt.connect(nodeId.c_str(), user, pass,
                          topicStatus.c_str(), 0, true, "offline");
   if (ok) {
     Serial.println(F("connected"));
     mqtt.publish(topicStatus.c_str(), "online", true);
     lastAlertMask = -1;
   } else {
     mqttFails++;
     Serial.print(F("failed, rc=")); Serial.print(mqtt.state());
     Serial.print(F(" (total ")); Serial.print(mqttFails); Serial.println(F(")"));
   }
 }

 void mqttService() {
   if (wifiState != WIFI_ST_CONNECTED) return;
   if (mqtt.connected()) { mqtt.loop(); return; }
   if (millis() - mqttLastTry < MQTT_RECONNECT_MS) return;
   mqttLastTry = millis();
   mqttConnect();
 }

 static void numOrNull(char* out, size_t sz, bool ok, float v, int dp) {
   if (ok) snprintf(out, sz, "%.*f", dp, v);
   else    snprintf(out, sz, "null");          // JSON has no NaN
 }

 void publishTelemetry(bool tempOk, float temp, float hum, bool luxOk, float lux) {
   if (!mqtt.connected()) return;

   char tb[12], hb[12], lb[12];
   numOrNull(tb, sizeof(tb), tempOk, temp, 2);
   numOrNull(hb, sizeof(hb), tempOk, hum, 2);
   numOrNull(lb, sizeof(lb), luxOk, lux, 1);

   time_t now  = time(nullptr);
   bool   tsOk = now > TIME_VALID_MIN;

   char payload[320];
   snprintf(payload, sizeof(payload),
     "{\"ts\":%ld,\"ts_valid\":%s,\"uptime_ms\":%lu,\"seq\":%lu,"
     "\"temp_c\":%s,\"hum_pct\":%s,\"lux\":%s,"
     "\"sound_avg_db\":%.1f,\"sound_peak_db\":%.1f,\"sound_calibrated\":%s,"
     "\"alerts\":\"%s%s%s\",\"rssi\":%d}",
     (long)(tsOk ? now : 0), tsOk ? "true" : "false",
     millis(), (unsigned long)(++seq),
     tb, hb, lb,
     soundAvgDb, soundMaxDb, (MIC_CAL_DB != 0.0f) ? "true" : "false",
     alertTemp ? "T" : "-", alertLight ? "L" : "-", alertSound ? "S" : "-",
     WiFi.RSSI());

   if (!mqtt.publish(topicTelemetry.c_str(), payload)) {
     mqttFails++;
     Serial.println(F("# MQTT publish failed (telemetry)"));
   }
 }

 // Retained alert-state message, published only when the state changes.
 void publishAlertState() {
   int mask = (alertTemp ? 1 : 0) | (alertLight ? 2 : 0) | (alertSound ? 4 : 0);
   if (mask == lastAlertMask) return;
   if (!mqtt.connected()) return;
   lastAlertMask = mask;

   char payload[96];
   snprintf(payload, sizeof(payload),
     "{\"temp\":%s,\"light\":%s,\"sound\":%s}",
     alertTemp  ? "true" : "false",
     alertLight ? "true" : "false",
     alertSound ? "true" : "false");
   mqtt.publish(topicAlert.c_str(), payload, true);
 }

 // ============================ SETUP ==========================
 void setup() {
   Serial.begin(115200);
   delay(800);
   Serial.println();
   Serial.println(F("Classroom Environment Monitor - Stage 2"));
   Serial.flush();   // if this line never appears, the hang is before setup()

   pinMode(BUZZER_PIN, OUTPUT);
   noTone(BUZZER_PIN);

   analogReadResolution(12);
   analogSetPinAttenuation(MIC_PIN, ADC_11db);   // full 0-3.3V range
   // Touch shares LCD_RS/LCD_CS and is read on ADC1; same range as the mic.
   analogSetPinAttenuation(TFT_DC, ADC_11db);
   analogSetPinAttenuation(TFT_CS, ADC_11db);

   // Panel first, so the splash is up while the rest of the boot runs.
   // tftBegin() only drives the parallel bus pins, so it cannot disturb
   // the idle I2C levels preflightBus() reads next.
   tftBegin();

   // Self-test before anything is brought up. Brings Wire up as a side
   // effect, so the sensor begin() calls below can use it directly.
   preflightBus();

   preflightDisplay();
   preflightSummary();
   tftPreflight();        // same report on the TFT, then the dashboard

   calibrateMicBias();
   Serial.printf("Mic DC bias: %.0f counts (%.2f V)\n",
                 micBias, micBias * ADC_VREF / ADC_MAX);

   if (sht3x.begin(SHT3X_ADDR)) {
     shtReady = true;
     Serial.printf("SHT3x ready at 0x%02X\n", SHT3X_ADDR);
     sht3x.heater(false);                        // heater adds self-heating error
   } else {
     Serial.printf("SHT3x NOT found at 0x%02X - try 0x45\n", SHT3X_ADDR);
   }

   if (lightMeter.begin(BH1750::CONTINUOUS_HIGH_RES_MODE)) {
     bh1750Ready = true;
     Serial.printf("BH1750 ready at 0x%02X\n", BH1750_ADDR);
   } else {
     Serial.printf("BH1750 NOT found at 0x%02X - try 0x5C\n", BH1750_ADDR);
   }

   WiFi.mode(WIFI_STA);
   WiFi.disconnect();
   wifiState      = WIFI_ST_SCAN;
   wifiStateSince = millis();

   mqttInit();
   configTime(GMT_OFFSET_SEC, DST_OFFSET_SEC, NTP_SERVER);

   startAlarm(2, 1500);                          // boot chirp / buzzer self-test
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
 void loop() {
   serviceAlarm();
   handleWifi();
   mqttService();

   if (millis() - lastRead < READ_INTERVAL_MS) return;
   lastRead = millis();

   // temp / humidity
   float temp = NAN, hum = NAN;
   bool tempOk = false;
   if (shtReady) {
     temp   = sht3x.readTemperature();
     hum    = sht3x.readHumidity();
     tempOk = !isnan(temp) && !isnan(hum);
     if (!tempOk) {
       shtFails++;
       Serial.print(F("# SHT3x read failed, total: ")); Serial.println(shtFails);
     }
   }

   // light
   float lux   = readLux();
   bool  luxOk = (lux >= 0);
   if (!luxOk && bh1750Ready) {
     luxFails++;
     Serial.print(F("# BH1750 read failed, total: ")); Serial.println(luxFails);
   }

   // sound
   readSound();

   evaluateAlarms(tempOk, temp, luxOk, lux, soundMaxDb);
   publishAlertState();

   bool wifiUp = (wifiState == WIFI_ST_CONNECTED);
   printPanel(tempOk, temp, hum, luxOk, lux, wifiUp);
   drawPanel (tempOk, temp, hum, luxOk, lux, wifiUp);

   // Serial CSV
   Serial.print(millis());                  Serial.print(',');
   if (tempOk) Serial.print(temp, 2); else Serial.print("NaN");
   Serial.print(',');
   if (tempOk) Serial.print(hum, 2);  else Serial.print("NaN");
   Serial.print(',');
   if (luxOk)  Serial.print(lux, 1);  else Serial.print("NaN");
   Serial.print(',');
   Serial.print(soundAvgDb, 1);             Serial.print(',');
   Serial.print(soundMaxDb, 1);             Serial.print(',');
   Serial.print(alertTemp  ? "T" : "-");
   Serial.print(alertLight ? "L" : "-");
   Serial.println(alertSound ? "S" : "-");

   // MQTT telemetry (no-op if broker link is down)
   publishTelemetry(tempOk, temp, hum, luxOk, lux);
 }

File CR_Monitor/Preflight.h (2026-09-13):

/* Preflight self-test - Classroom Environment Monitor
 *
 * Runs before the sensors, display and network are brought up, and prints
 * a PASS/FAIL report for each subsystem. Nothing here halts the boot: a
 * classroom node should still come up and report what it can, so a failure
 * is printed and the sketch carries on.
 *
 * Included AFTER TFT_Panel.h so the tft object exists for the display test.
 *
 * The mic thresholds encode a real failure we hit on this board: with the
 * 3V3 wire off, the sensor rail still floats to ~2.5 V, back-fed through the
 * chips ESD protection diodes from the I2C lines. Everything looks powered
 * and nothing works. The MAX4466 idles at VCC/2, so its DC bias is the
 * cheapest voltmeter we have on that rail - see PF_MIC_PHANTOM_* below.
 */

// Set to 0 to compile the self-test out entirely. If the board stops
// booting after a change here, flip this to 0 and re-upload: if it still
// will not boot, the fault is not in this file.
#define PREFLIGHT_ENABLE 1

// The panel ID readback in [5] drives the parallel bus and reads it back.
// Set to 0 if the display is not wired yet, or if [5] is the last line you
// see before a hang.
#define PREFLIGHT_DISPLAY 1

// Expected MAX4466 DC bias, in raw 12-bit counts.
//   VCC 3.3 V -> 1.65 V -> 2048 counts ideal.
//   The S3 uncalibrated ADC at 11 dB reads a few % low, so ~1900-2050 real.
#define PF_MIC_OK_LO        1800
#define PF_MIC_OK_HI        2150
//   VCC 2.5 V -> 1.25 V -> ~1550 counts. The diode-drop signature.
#define PF_MIC_PHANTOM_LO   1400
#define PF_MIC_PHANTOM_HI   1700
#define PF_MIC_DEAD          100   // below this, nothing is driving the pin

enum PfResult { PF_PASS, PF_WARN, PF_FAIL, PF_SKIP };

static PfResult pfBus = PF_SKIP, pfSensors = PF_SKIP,
                pfMicR = PF_SKIP, pfDisp = PF_SKIP;

// What the mic measurement looked like, kept raw so the cross-check pass
// can reinterpret it once the sensor result is known.
enum PfMicCat { MIC_OK, MIC_DEAD, MIC_PHANTOM, MIC_LOW, MIC_ODD };
static PfMicCat pfMicCat   = MIC_OK;
static uint16_t pfMicBias  = 0;
static float    pfMicVolts = 0;
static bool     pfMicIsMic = false;   // fault is the mic, not the shared rail

static const char* pfName(PfResult r) {
  switch (r) {
    case PF_PASS: return "PASS";
    case PF_WARN: return "WARN";
    case PF_FAIL: return "FAIL";
    default:      return "SKIP";
  }
}

// ---------------------------------------------------------------
// [1] Bus lines, read BEFORE Wire.begin() so we see the real idle state.
// No internal pull-ups: a powered, correctly wired breakout holds both
// lines high through its own ~10k. Enabling the internal pull-ups here
// would mask exactly the fault we are looking for.
// ---------------------------------------------------------------
static void pfCheckLines() {
  Serial.println(F("[1] I2C bus lines"));

  // Pull DOWN internally (~45k) and see if something outside still wins.
  // A plain INPUT floats, and a floating CMOS input reads HIGH as often as
  // not - which reports a pull-up that is not there. Against the internal
  // pulldown, a real 10k pull-up divides to ~2.7 V and reads HIGH; nothing
  // externally connected reads LOW. That distinction is the whole test.
  pinMode(I2C_SDA, INPUT_PULLDOWN);
  pinMode(I2C_SCL, INPUT_PULLDOWN);
  delay(10);
  int sda = digitalRead(I2C_SDA);
  int scl = digitalRead(I2C_SCL);

  Serial.printf("    SDA (GPIO%d): %s\n", I2C_SDA, sda ? "HIGH" : "LOW");
  Serial.printf("    SCL (GPIO%d): %s\n", I2C_SCL, scl ? "HIGH" : "LOW");

  if (sda && scl) {
    pfBus = PF_PASS;
    Serial.println(F("    PASS - external pull-ups present, both lines land"));
  } else {
    pfBus = PF_FAIL;
    Serial.println(F("    FAIL - a LOW line has no pull-up holding it up."));
    Serial.println(F("      -> module unpowered, wire not landing, or line"));
    Serial.println(F("         shorted to GND. Fix this first; a scan cannot"));
    Serial.println(F("         succeed while a bus line is stuck low."));
  }
}

// ---------------------------------------------------------------
// [2] Who is actually on the bus, and [3] are they where we expect.
// ---------------------------------------------------------------
static void pfCheckDevices() {
  Serial.println(F("[3] I2C device scan"));

  Wire.begin(I2C_SDA, I2C_SCL);
  Wire.setClock(100000);
  delay(50);

  bool sht = false, bh = false, shtAlt = false, bhAlt = false;
  uint8_t found = 0;

  for (uint8_t addr = 1; addr < 127; addr++) {
    Wire.beginTransmission(addr);
    if (Wire.endTransmission() != 0) continue;
    found++;
    Serial.printf("    0x%02X", addr);
    if      (addr == 0x44) { Serial.print(F("  SHT3x"));              sht    = true; }
    else if (addr == 0x45) { Serial.print(F("  SHT3x (ADR high)"));   shtAlt = true; }
    else if (addr == 0x23) { Serial.print(F("  BH1750"));             bh     = true; }
    else if (addr == 0x5C) { Serial.print(F("  BH1750 (ADDR high)")); bhAlt  = true; }
    Serial.println();
  }

  if (found == 0) Serial.println(F("    nothing responded"));
  Serial.printf("    %u device(s)\n", found);

  Serial.println(F("[4] Expected sensors"));
  Serial.printf("    SHT3x  @0x%02X : %s\n", SHT3X_ADDR,
                sht ? "PRESENT" : (shtAlt ? "WRONG ADDRESS (0x45)" : "MISSING"));
  Serial.printf("    BH1750 @0x%02X : %s\n", BH1750_ADDR,
                bh  ? "PRESENT" : (bhAlt  ? "WRONG ADDRESS (0x5C)" : "MISSING"));

  if (sht && bh) {
    pfSensors = PF_PASS;
    Serial.println(F("    PASS"));
  } else if (shtAlt || bhAlt) {
    pfSensors = PF_WARN;
    Serial.println(F("    WARN - device found at the alternate address."));
    Serial.println(F("      -> tie that module ADDR/ADR pin to GND, or change"));
    Serial.println(F("         the address in the sketch to match."));
  } else {
    pfSensors = PF_FAIL;
    Serial.println(F("    FAIL - expected sensors did not answer."));
    if (pfMicR == PF_FAIL || pfMicR == PF_WARN) {
      // Power is the more likely story. Do not send anyone hunting for a
      // swapped wire while the rail is below what the parts need to run:
      // BH1750 needs 2.4 V, SHT3x 2.15 V.
      Serial.println(F("      -> the rail check above failed. Below ~2.4 V these"));
      Serial.println(F("         parts cannot run, but their pull-ups still hold"));
      Serial.println(F("         the bus high - which is what you are seeing."));
      Serial.println(F("         Fix the supply first; this is likely downstream."));
    } else if (found == 0 && pfBus == PF_PASS) {
      Serial.println(F("      -> lines idle high but nobody answers: check that"));
      Serial.println(F("         SDA and SCL are not swapped (SDA=8, SCL=9)."));
    }
  }
}
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

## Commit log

2026-09-13 Initial commit: classroom environment monitor
    ESP32-S3 node reading temperature/humidity (SHT3x), illuminance
    (BH1750) and sound level (MAX4466), publishing JSON telemetry over
    MQTT to a local Mosquitto/Node-RED/InfluxDB/Grafana stack.
    Sound is measured as a dB level only -- no audio is captured or
    transmitted -- and occupancy is bucketed rather than counted.
    Wi-Fi credentials in the sketch are placeholders; add a .gitignore
    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
2026-09-13 Add TFT dashboard, preflight self-test and hardware bring-up sketches
    Display: 3.5" 320x480 parallel panel driven by TFT_eSPI. The controller
    is ILI9481, not the HX8357D originally assumed -- the pin map was right
    all along, the init sequence was not, which is why the screen stayed
    white. The panel also powers up with its colours inverted, so tftBegin()
    flips it once rather than inverting the palette by hand.
    TFT_Panel.h draws four cards (temperature, humidity, light, sound) on a
    dark surface, each with an icon that recolours with its value: green
    inside the band, amber within 8% of a limit or on a failed read, red
    when alarming. A failed sensor shows dashes rather than a stale number.
    Pre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
    [CR_Monitor.ino, I2C_Scan.ino, Preflight.h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]
2026-09-14 Add project documentation site and remove duplicate setup guide
    Five HTML pages under docs/ covering architecture, the pin map, firmware
    internals, the MQTT contract and the build walkthrough. Linked from the
    README and servable as a GitHub Pages site from the docs/ folder.
    SETUP_GUIDE.md was a byte-for-byte duplicate of SETUP_GUIDE.txt and is
    removed. The InfluxDB credentials that were pasted into the remaining
    guide are replaced with placeholders.
2026-09-20 Add boot splash and printable enclosure
    The panel now comes up before the bus self-test and holds the APU mark on
    white with the author's name for two seconds. tftBegin() only touches the
    parallel bus pins, so moving it ahead of preflightBus() leaves the idle I2C
    levels alone. Logo_APU.h is the mark baked to RGB565 against white, since
    the sketch has no PNG decoder at boot; tools/mklogo.py regenerates it.
    CR_Monitor_Enclosure holds the Blender model, the parametric build script,
    exported STLs for all seven printed parts, and the dimension and layout
    renders.
    Broker IP moved to 192.168.1.8.
    [01_rear_tray.stl, 02_front_bezel.stl, 03_battery_cradle.stl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]
